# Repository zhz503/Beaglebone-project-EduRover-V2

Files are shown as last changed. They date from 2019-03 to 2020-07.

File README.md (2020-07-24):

# BeagleBone project--EduRover(version2)

### Project Description:

This is an application of the embedded system: Beaglebone. EduRover is originally designed by James Strawson(jstrawso@eng.ucsd.edu) in the Drone Lab and Coordinated Robotics Lab, @UCSD. In version 2, we made some modification on it, redesigned some part of it. In our case, high torque motors could be perfectly embedded into our design and with the higher level control algorithm, we can manually drive EduRover in different modes. Meanwhile, with the high torque motors, we can balance EduRover by using only two wheels when it faces the wall.      

For more details, please check the report:

https://github.com/zhz503/Beaglebone-project-EduRover-V2/blob/master/doc/EduRover_report.pdf

### Team Member:

Zhaoliang Zheng (zhz503@eng.ucsd.edu)

Dominique E. Meyer (demeyer@ucsd.edu)

Neal Bansal (nkbansal@ucsd.edu)

Pengcheng Cao (p5cao@eng.ucsd.edu)

Junchao Lin (jul025@eng.ucsd.edu)

### EduRover V2:
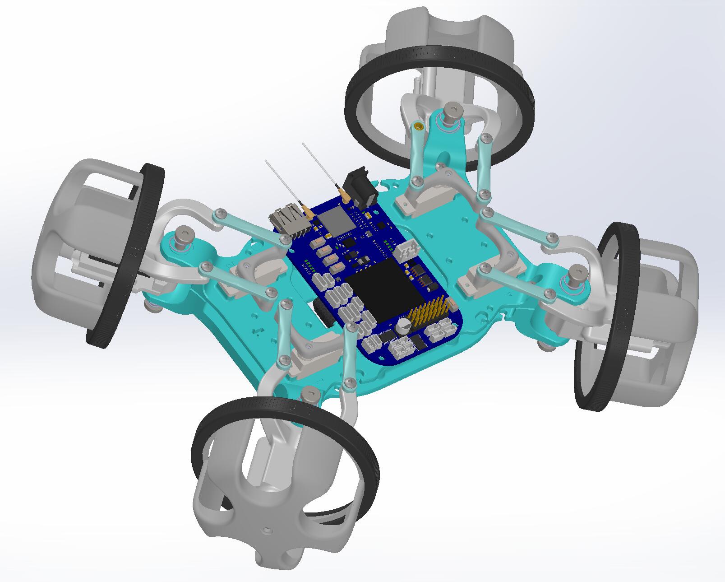
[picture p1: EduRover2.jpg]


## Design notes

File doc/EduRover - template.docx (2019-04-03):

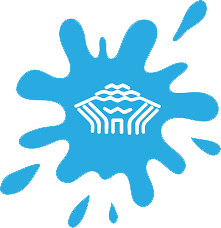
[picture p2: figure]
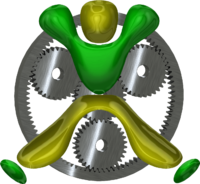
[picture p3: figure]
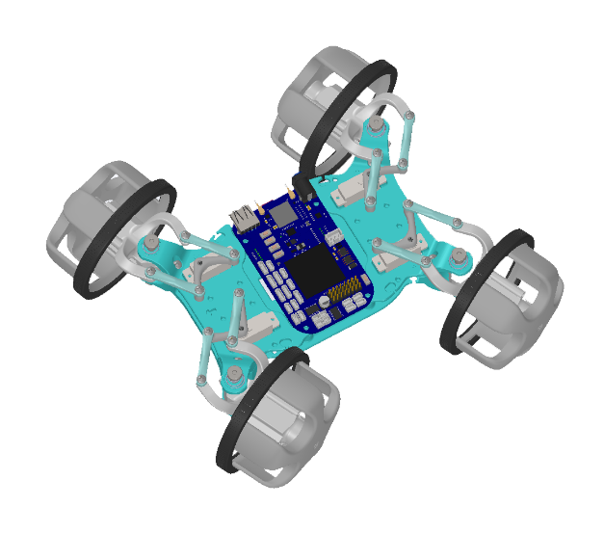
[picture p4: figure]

TEAM MEMBERS:

Zhaoliang Zheng (zhz503@eng.ucsd.edu)

Dominique Meyer (demeyer@ucsd.edu)

Neal Bansal (nkbansal@ucsd.edu)

Pengcheng Cao (p5cao@eng.ucsd.edu)

Junchao Lin (jul025@eng.ucsd.edu)

BeagleBone Project

# EduRover V2

# 0 Introduction

This is an application of the embedded system: Beaglebone. EduRover is originally designed by James Strawson (jstrawso@eng.ucsd.edu) in the Done Lab@UCSD and Coordinated Robotics Lab@UCSD. In version 2, we made some modification on it, redesigned some part of it. In our case, high torque motors could be perfectly embedded into our design and with the higher level control algorithm, we can manually drive EduRover in different modes. Meanwhile, with the high torque motors, we can balance EduRover by using only two wheels when it faces the wall.

# 1 Structure

This chapter describes the structure and some hardware of EduRover as well as the properties of these components. All the Solidworks files can be found in the link: https://github.com/zhz503/Beaglebone-project-EduRover-V2/tree/master/Edu%20Rover%20Solidworks%20Version2

1.1 Configuration in different modes
The figure 1-1 shows the structure of EduRover and in the balance condition.

The figure 1-2 shows the different four-wheeled EduRover driving mode.

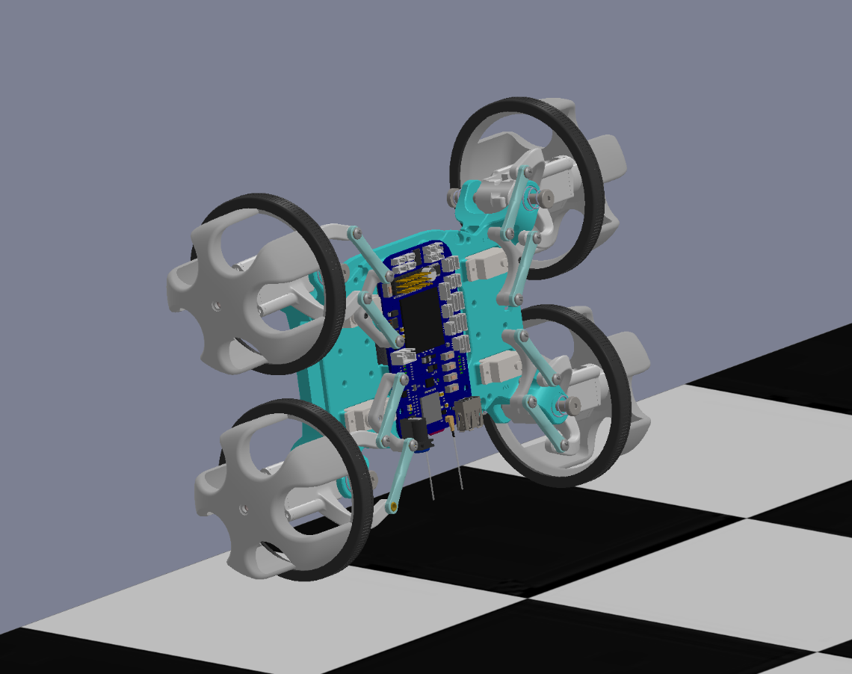
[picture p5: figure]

Figure 1-1 Balance Configuration Mode

(a) (b)

(c) (d)

Figure 1-2 (a) is Spinning Mode, (b) is Normal-car Mode, (c) is Quarter Turn Mode, (d) is Sidling Mode

## 1.2 Sensors and Actuators

Table 1-1 Sensors

Sensor | Output | Unit
Encoder | Angle | rad or deg
IMU: Gyroscope | Angular velocity | deg/sec
IMU: Accelerometer | Linear velocity | m/sec

Table 1-2 Actuators

Actuator | Output | Unit
Servo Motor | Position or duty circle | %
DC Motor | PWM | %

The illustration of DC motor[1] and Servo Motor can be found in appendix A and reference.

# 2 Mathematical Modeling

This chapter describes the mathematical model and motion equations of EduRover. Based on the basic knowledge, the EduRover balance mode can be simplified as a two-wheeled inverted pendulum model[2], and EduRover four-wheeled normal-car mode can be simplified as Ackermann drive (bicycle) model. Spining Mode, Quarter Turn Mode, Sidling Mode can be simplified as Omni Wheel model.

## 2.1 Notation

Items | Parameter | Value | Unit | Meaning
EduRover Parameter | g | 9.81 | m/sec^2 | Gravity acceleration
| m | 0.03852 | kg | Wheel weight
| R | D/2= 0.0425 | m | Wheel radius
| J_w | mR^2 /2 | kgm^2 | Wheel inertia moment
| M | 0.6 | kg | Body weight
| W | 0.150 | m | Body width
| D | 0.048 | m | Body depth
| H | 0.18282 | m | Body height
| L | 0.08869 | m | Distance of the center of mass from the wheel axle
| J_ψ | ML^2 /3 | kgm^2 | Body pitch inertia moment
| J_ϕ | M(W^2 +D^2 )/12 | kgm^2 | Body yaw inertia moment
| f_m | 0.0022 | | Friction coefficient between body & DC motor
| f_w | Depends[4]:0.1 | | Rolling Friction between wheel & floor
DC motor | T_(or) | 0.1765 | Nm | Motor torque
| I_m | 1.6 | A | Motor working current
| J_m | 2.7565e^(-) 7 | kgm^2 | DC motor inertia moment
| R_m | 2.7 | Ω | DC motor resistance
| K_b | 7.407e^(-) 4 | Vsec/rad | DC motor back EMF constant
| K_t | T_(or) /I_m | Nm/A | DC motor torque constant
| n | 99 | | Gear ratio

Note:

DC motor parameters can be found in [1].

f_m ,f_w are hard to verify, so they are a approximation.

[4] Rubber & Concrete(Dry)

## 2.2 Two-wheeled Inverted Pendulum Model and Differential-drive Model

The EduRover can be simplified as a two-wheeled inverted pendulum model, as described in Figure 2.2-1

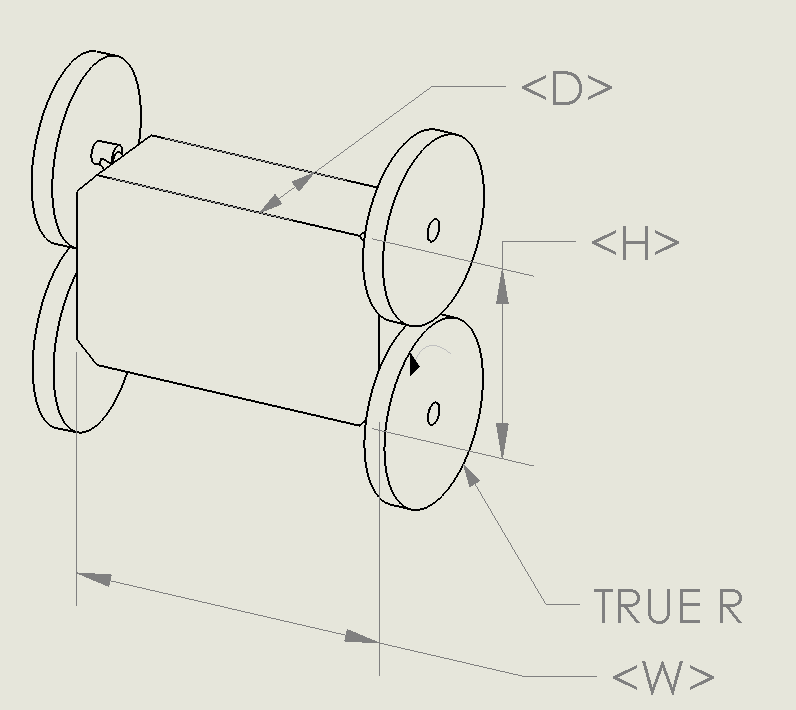
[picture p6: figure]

Figure 2.2-1 Two-wheeled Inverted Pendulum Model

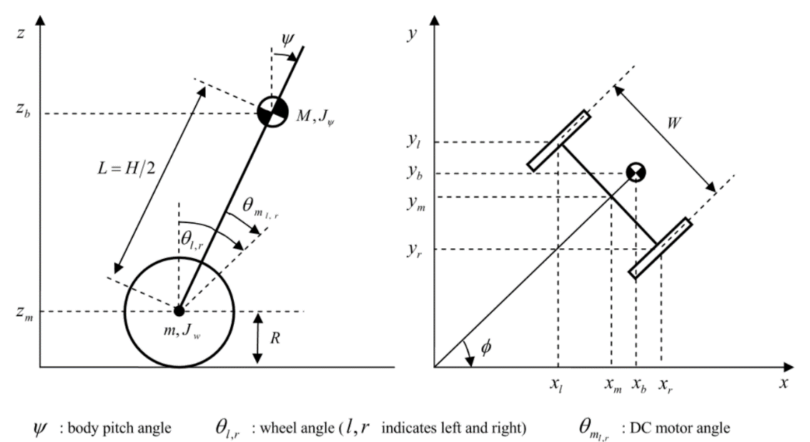
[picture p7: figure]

Figure 2.2-2 Side view and plane view of the model

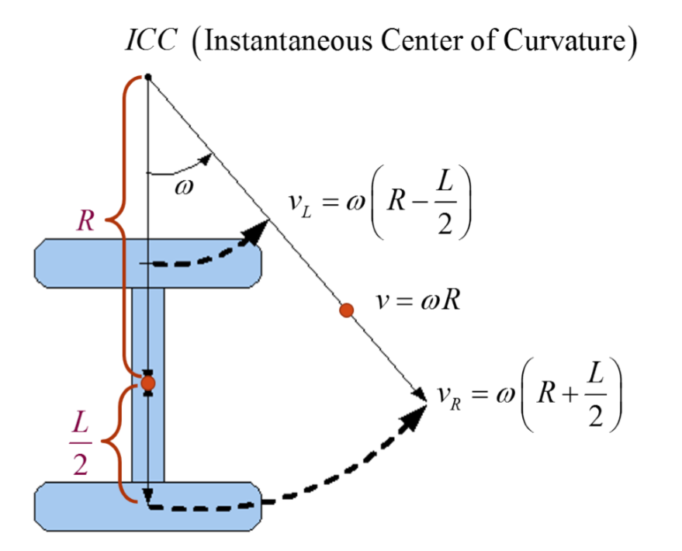
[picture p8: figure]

Figure 2.2-3 Differential-drive Model

### 2.2.1 Motion equations of two-wheeled inverted pendulum

We can derive motion equations for inverted pendulum based on figure 2.2-2 and the differential model in figure 2.2-3 differential-drive model [3].

[F_θ , F_ψ , F_ϕ ]^T =[1/2(F_l +F_r ), F_ψ , R/W(F_r -F_l )]^T

[x_m , y_m , z_m ]^T =[Rθcosϕ, Rθsinϕ, R]^T

[θ, ϕ]^T = [1/2(θ_l +θ_r ), R/W(θ_r -θ_l )]^T

[x_l , y_l , z_l ]^T =[x_m -W/2sinϕ, y_m +W/2cosϕ, z_m ]^T

[x_r , y_r , z_r ]^T =[x_m +W/2sinϕ, y_m -W/2cosϕ, z_m ]^T

[x_b , y_b , z_b ]^T =[x_m +Lsinψcosϕ, y_m +Lsinψsinϕ, z_m +Lcosψ]^T

Where,

θ : average rotational angle of left and right wheel

ψ : Body pitch angle

ϕ : Body yaw angle

Based on the kinetic energy theorem and the potential energy theorem, the translational kinetic energy E_(k1) and the rotational kinetic energy E_(k2) , the potential energy E_p are:

E_(k1) =1/2m(x_l ^2 +y_l ^2 +z_l ^2 )+1/2m(x_r ^2 +y_r ^2 +z_r ^2 )+1/2M(x_b ^2 +y_b ^2 +z_b ^2 )

E_(k2) =1/2J_w θ_l ^2 +1/2J_w θ_r ^2 +1/2J_ψ ψ^2 +1/2J_ϕ ϕ^2 +1/2n^2 J_m (θ_l -ψ)^2 +1/2n^2 J_m (θ_r -ψ)^2

E_p =mgz_l +mgz_r +Mgz_b

Note: the last two terms in E_(k2) equation are the rotational kinetic energy of armature in the left and right DC motor.

### 2.2.2 Lagrangian equations

Based on the Lagrangian method, The Lagrangian L has the following expression:

L=E_(k1) +E_(k2) -E_p

We use the variables θ,ψ,ϕ as the generalized coordinate. The Lagrangian equation can be derived as:

d/(dt)((∂L)/(∂ θ))-(∂L)/(∂θ)=F_θ

d/(dt)((∂L)/(∂ ψ))-(∂L)/(∂ψ)=F_ψ

d/(dt)((∂L)/(∂ ϕ))-(∂L)/(∂ϕ)=F_ϕ

Expand the equations ()-(), we can derive the following equations, the whole derivation is in the Appendix:

((2m+M)R^2 +2J_w +2n^2 J_m )θ+(MLRcosψ-2n^2 J_m )ψ-MLRsinψ ψ^2

-((2m+M)R^2 θ+MLRsinψ)ϕ^2 =F_θ

(ML^2 +J_ψ +2n^2 J_m )ψ+(-2n^2 J_m +MLRcosψ)θ-MgLsinψ

-(MLRθ+ML^2 sinψ)ϕ^2 cosψ=F_ψ

((mW^2)/2+(W^2)/(2R^2)(J_w +n^2 J_m )+J_ϕ +2MLRθsinψ+(2m+M)R^2 θ^2 )ϕ+2(2m+M)R^2 θθϕ+2ML^2 sinψcosψ ψϕ+2MLRϕ(θsinψ+cosψ θψ)=F_ϕ

Considering the rolling friction between motor and wheel as well as the friction between wheel and floor, the generalized force are:

F_l =nK_t i_l +f_m (ψ-θ_l )-f_w θ_l

F_r =nK_t i_r +f_m (ψ-θ_r )-f_w θ_r

F_ψ =-nK_t i_r -nK_t i_l -f_m (ψ-θ_r )-f_m (ψ-θ_l )

Where i_(l,r) is DC motor current.

Since the input of our system is voltage of DC motor, in the above equations, we cannot used current i_(l,r) directly. Therefore, we have to derive the relationship between current i_(l,r) and voltage ν_(l,r) . From DC motor model, The applied voltage equals the voltage drop across the coil resistance, R, and the inductor, L, plus the back-EMF[5], which is as follows:[4]:

ν_(l,r) =i_(l,r) R_m +L_m (di_(l,r))/(dt)+K_b (ψ-θ_(l,r) )

Where, R_m : DC motor resistance, L_m : DC motor inductance.

For the steady-state torque-speed relationship, L_m has no effect, so L_m term is negligible and is approximated as zero. Therefore, rewrite equation() as:

i_(l,r) =(ν_(l,r) -K_b (ψ-θ_(l,r) ))/(R_m)

When substitute the equation() to equations()-(), the generalized force can be expressed as the function of voltage:

F_θ =α/2(ν_l +ν_r )-(β+f_w )θ+βψ

F_ψ =-α(ν_l +ν_r )+2βθ-2βψ

F_ϕ =R/Wα(ν_l -ν_r )-(β+f_w )ϕ

Where, α=(nK_t)/(R_m), β=(nK_t K_b)/(R_m)+f_m

### 2.2.3 State equation linearization

So far, we’ve had all the equations we need. At the balance point, when the body angle ψ changes at about ±5^(°) , equation() can be linearized. In this case, ψ approximates to be 0, meaning that sin ψ≈0,cosψ≈1 , and ψ^2 ≈0 . The linearized Lagrangian equations() can be rewritten as follows:

((2m+M)R^2 +2J_w +2n^2 J_m )θ+(MLRcosψ-2n^2 J_m )ψ=F_θ

(ML^2 +J_ψ +2n^2 J_m )ψ+(MLR-2n^2 J_m )θ-MgLψ=F_ψ

((mW^2)/2+(W^2)/(2R^2)(J_w +n^2 J_m )+J_ϕ )ϕ=F_ϕ

Now, we can combine the equ()-() and the equations()-(), and rewrite these equations in matrix form:

{E[θψ]+F[θψ]+G[θψ]=H[ν_l ν_r ]Iϕ+Jϕ=K(ν_l -ν_r )

Where,

E=[(2m+M)R^2 +2J_w +2n^2 J_m , MLRcosψ-2n^2 J_m MLR-2n^2 J_m , ML^2 +J_ψ +2n^2 J_m ]

F=[β+f_w , -β-2β, 2β] , G=[0, 00, -MgL] , H=[α/2, α/2-α, -α]

I= (mW^2)/2+(W^2)/(2R^2)(J_w +n^2 J_m )+J_ϕ

J=β+f_w

K= R/Wα

Now, we can consider x_1 =[θ, ψ, θ, ψ]^T , x_2 =[ϕ, ϕ] as the state, u=[ν_l , ν_r ]^T as input, we can rewrite equations() as state space equations form:

x_1 =A_1 x_1 +B_1 u

x_2 =A_2 x_2 +B_2 u

The state space realization:

A_1 =[0, 00, 0, 1, 00, 10, A_1 (3,2)0, A_1 (4,2), A_1 (3,3), A_1 (3,4)A_1 (4,3), A_1 (4,4)] , B_1 =[0, 00, 0B_1 (3), B_1 (3)B_1 (4), B_1 (4)]

A_2 =[0, 10, -J/I] , B_2 =[0, 0-K/I, K/I]

Where, in the MATLAB:

det(E)=E(1,1)E(1,2)-E(1,2)^2

A_1 (3,2)=-MgLE(1,2)/det⁡(E)

A_1 (4,2)=MgLE(1,1)/det⁡(E)

A_1 (3,3)=-((β+f_w )E(2,2)+2βE(1,2))/(det(E))

A_1 (4,3)=((β+f_w )E(1,2)+2βE(1,1))/(det(E))

A_1 (3,4)=(β(E(2,2)+2E(1,2)))/(det(E))

A_1 (4,4)=-(β(E(1,2)+2E(1,1)))/(det(E))

B_1 (3)=(α(E(2,2)/2+E(1,2)))/(det(E))

B_1 (4)=-(α(E(1,2)/2+E(1,1)))/(det(E))

# 3 Control system design

## 3.1 Control System Theory

### 3.1.1 Input & Output

A. Balance Mode

Input : ν= [ν_l , ν_r ]^T

Output: x=[θ ψ θ ψ]^T

B. Four-wheeled modes

Input: u=[flag K_m K_s ]

Output: x=[Mo_1234 Ser_1234 ]

### 3.1.2 Stability

(not yet finish)

## 3.2 Controller design

### 3.2.1 Equivalent system for balance mode

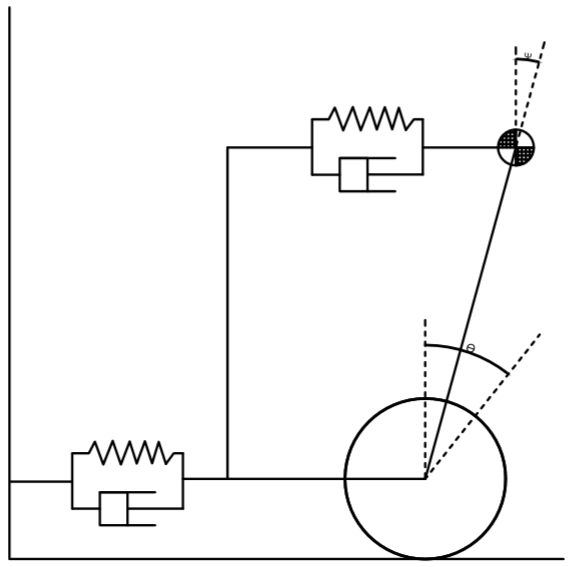
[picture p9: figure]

Figure 3.2-1

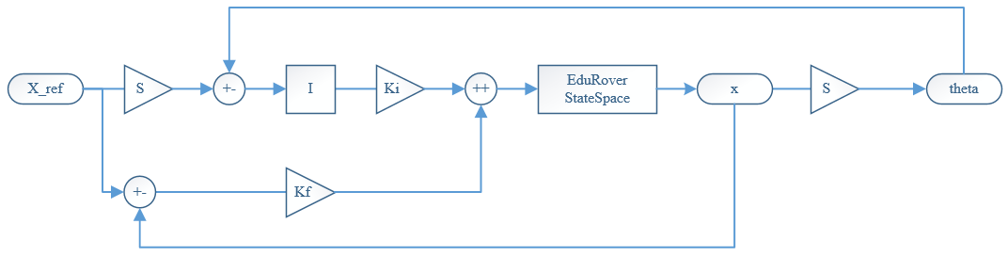
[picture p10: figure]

Figure 3.2-2

### 3.2.2 Simulation

A. Balance Mode

The EduRover balance mode can only be activated when it faces the wall. In the simulation, we only consider the small angle approximation, which is around 5^(°) . We can set the initial condition: ψ=5^(°) . The simulation runs in Simulink. The result is as follows.

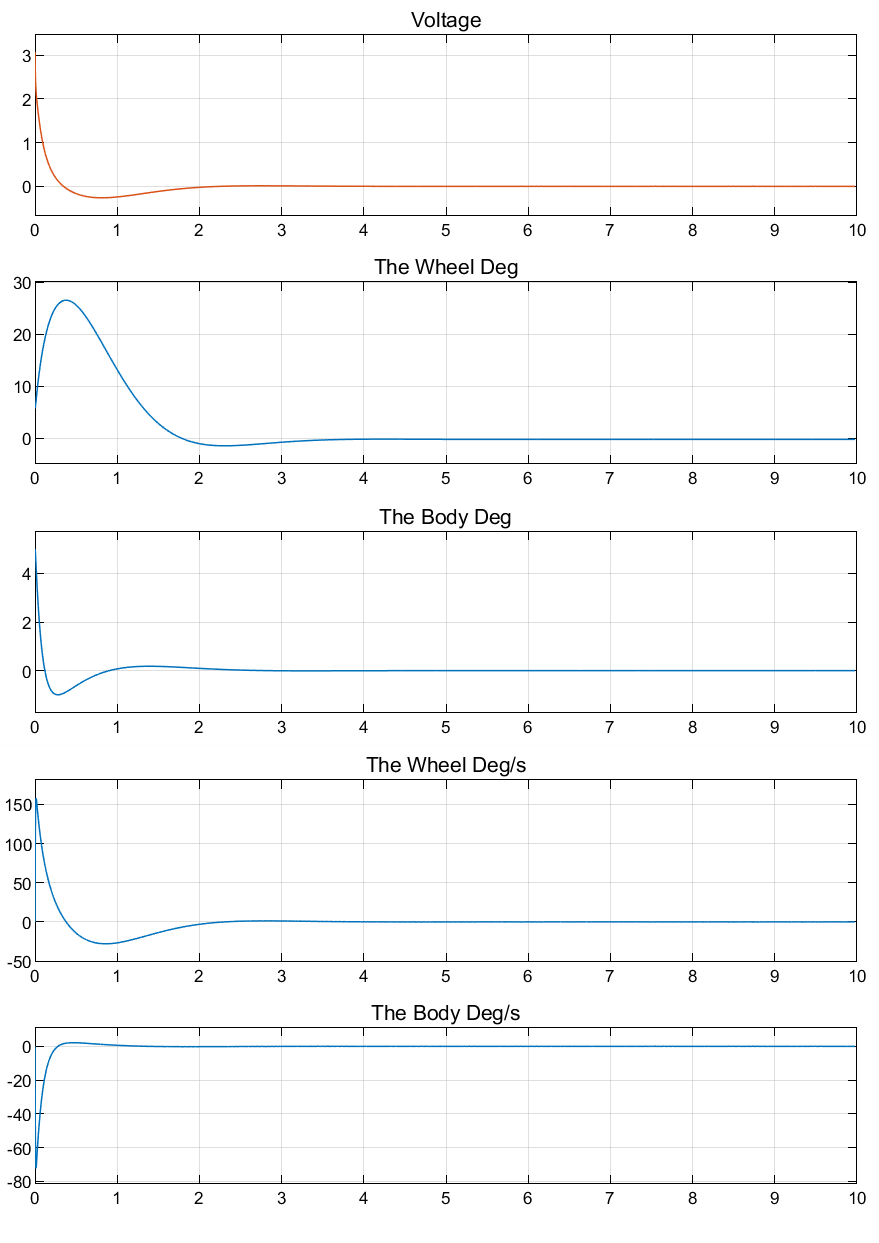
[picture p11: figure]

Figure 3.2-1

B. Four-wheeled driving mode

In the four-wheeled driving mode, four situation has to be consider: (a) Spinning mode, (b) Normal-car mode, (c) Quarter-turn mode, (d) Sidling mode. To switch from different modes, we have set up a servo logic for these four different modes.

For manual control, we want to minimize the number of inputs as much as possible. The figure 3.2-2 shows that the servo logics in Simulink. In this servo logics, the flag constant controls the logics switching between different modes. Flag(1): Spinning Mode, flag(2): Normal Car Mode, flag(3): Quarter Turn Mode, flag(4): Sidling Mode.

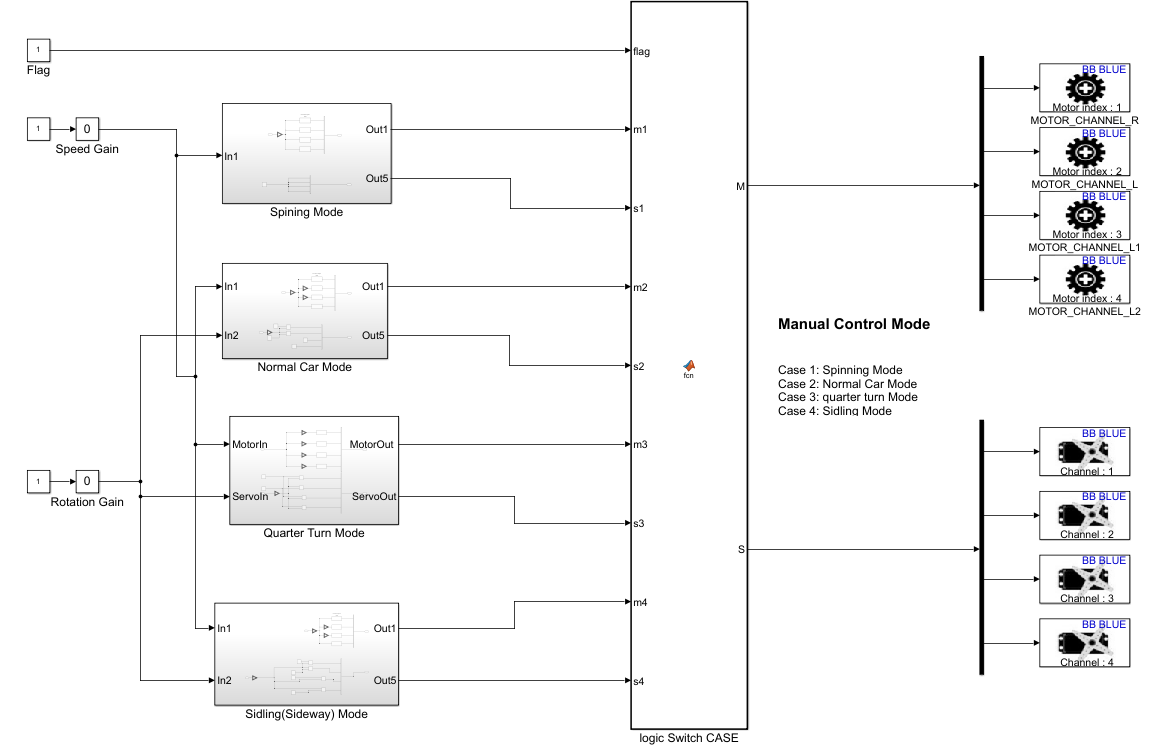
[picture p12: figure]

Figure 3.2-2 Servo logics

3.2.3 Real-world Experiment

A. Balance Mode

(not yet finish)

B. Four-wheeled driving mode

We can use the controller designed in Simulink to control the EduRover in real-time in real-world. The following video links can show you how it performs:

(1) https://github.com/zhz503/Beaglebone-project-EduRover-V2/blob/master/RW%20Simulink%20Control%20and%20Sensing/ManualControl.mp4
(2) https://github.com/zhz503/Beaglebone-project-EduRover-V2/blob/master/RW%20Simulink%20Control%20and%20Sensing/logics%20switch.MP4

# 4 Higher level application design

EduRover is a very decent platform for developer to do higher level application design. There are many applications right now.

In this report, I only list some of the on-going applications:

(1) Way points following based on Motion Capture system

(2) Path planning algorithm based on Motion Capture system

(3) Feature recognition based on web cam on board

(4) ORB-SLAM based on RGBD camera

## 4.1 Way points following based on Motion Capture system

### 4.1.1 Closed loop feedback control

(not yet finish)

### 4.1.2 Motion Capture System

In this project, the motion capture system we used is VICON system. According to the description [5], Vicon are the premier solution for UAV and Robotic studies because we understand what is important; A highly accurate system that provides low latency data that is easy to use. With our turnkey approach and easy to access our DataStream (via TCP, UDP, etc.) users can easily integrate accurate Vicon data into virtually any control system.

### 4.1.3 PID Control Algorithm

This PID control algorithm is designed by Dominique Meyer, which is available in the Github: https://github.com/zhz503/Beaglebone-project-EduRover-V2/tree/master/way_points%20following

## 4.2 Path planning Algorithm on board

### 4.2.1 Workflow

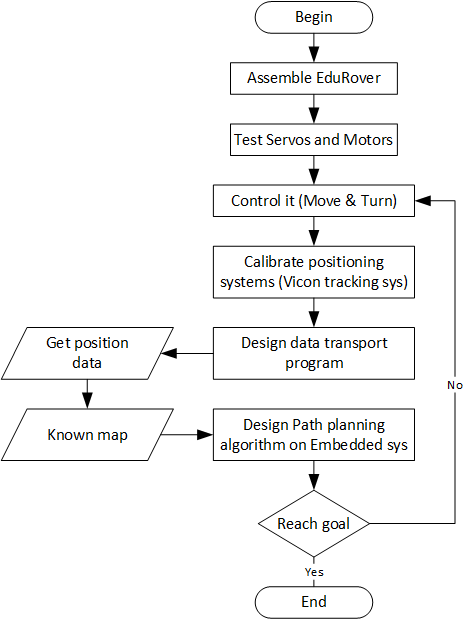
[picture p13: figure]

Figure 4-1

# Appendix A Table 1-3 Servo Motor Properties

Table 1-3 Servo Motor Properties

Product | Seller | Link | No-Load Speed @ 4.8V (sec/60°) | Price | Qty | Price/Unit
HS-45HB | ServoCity | https://www.servocity.com/hs-45hb-servo | 0.14 | $15.99 | 1 | $15.99
RB-Fit-03 | RobotShop | https://www.robotshop.com/en/9g-micro-servo-motor-4-8v.html#Supplier-Product-Code | 0.12 | $3.56 | 1 | $3.56
Miuzei SG90 | Amazon | https://www.amazon.com/Micro-Helicopter-Airplane-Remote-Control/dp/B072V529YD?ref_=fsclp_pl_dp_1&th=1 | 0.09 | $17.99 | 10 | $1.80
Seamuing MG90S | Amazon | https://www.amazon.com/dp/B07F7VJQL5/ref=psdc_2234131011_t2_B072V529YD?th=1 | 0.11 | $20.99 | 6 | $3.50
SG90 Micro Servo | Amazon | https://www.amazon.com/dp/B07F2XDZZ7/ref=psdc_2234131011_t2_B072V529YD?th=1 | 0.1 | $19.99 | 10 | $2.00

# Appendix B The derivation of Lagrangian equations

{x_l =Rθcosϕ-Wsinϕ/2x_r =Rθcosϕ+Wsinϕ/2x_b =Rθcosϕ+Lsinψcosϕ{x_l =Rθcosϕ-Rθsinϕ ϕ-Wϕcosϕ/2x_r =Rθcosϕ-Rθsinϕ ϕ+Wϕcosϕ/2x_b =Rθcosϕ-Rθsinϕ ϕ+Lψcosψcosϕ-Lϕsinψsinϕ

x_l ^2 +x_r ^2 =2(Rθcosϕ-Rθsinϕ ϕ)^2 + W^2 ϕ^2 cos^2 ϕ/2

{y_l =Rθsinϕ+Wcosϕ/2y_r =Rθsinϕ-Wcosϕ/2y_b =Rθsinϕ+Lsinψsinϕ{y_l =Rθsinϕ+Rθcosϕ ϕ-Wϕsinϕ/2y_r =Rθsinϕ+Rθcosϕ ϕ+Wϕsinϕ/2y_b =Rθsinϕ+Rθcosϕ ϕ+Lψcosψsinϕ+Lϕsinψcosϕ

y_l ^2 +y_r ^2 =2(Rθsinϕ+Rθcosϕ ϕ)^2 + W^2 ϕ^2 sin^2 ϕ/2

{z_l =Rz_r =Rz_b =R+Lcosψ{z_l =0z_r =0z_b =-Lψsinψ

E_(k1) =1/2m(x_l ^2 +y_l ^2 +z_l ^2 )+1/2m(x_r ^2 +y_r ^2 +z_r ^2 )+1/2M(x_b ^2 +y_b ^2 +z_b ^2 )=?

{θ=1/2(θ_l +θ_r )ϕ=R/W(θ_r -θ_l ){θ_l =θ-W/(2R)ϕθ_r =θ+W/(2R)ϕ{θ_l =θ-W/(2R)ϕθ_r =θ+W/(2R)ϕ

{(θ_l -ψ)^2 =(θ-W/(2R)ϕ-ψ)^2 (θ_r -ψ)^2 =(θ+W/(2R)ϕ-ψ)^2 (θ_l -ψ)^2 +(θ_r -ψ)^2 =2(θ-ψ)^2 +(W/(2R)ϕ)^2

E_(k2) =1/2J_w θ_l ^2 +1/2J_w θ_r ^2 +1/2J_ψ ψ^2 +1/2J_ϕ ϕ^2 +1/2n^2 J_m (θ_l -ψ)^2 +1/2n^2 J_m (θ_r -ψ)^2 =?

E_p =mgz_l +mgz_r +Mgz_b =2mgR+Mg(R+Lcosψ)

L=E_(k1) +E_(k2) -E_p =?

(∂L)/(∂ θ)=1/2((2m+M)R^2 (2θ)+MLRψcosψ)+2J_w θ+2n^2 J_m (θ-ψ)

(∂L)/(∂θ)=?

d/(dt)((∂L)/(∂ θ))=?

(∂L)/(∂ ψ)=?

(∂L)/(∂ψ)=？

d/(dt)((∂L)/(∂ ψ))=？

(∂L)/(∂ ϕ)=？

(∂L)/(∂ϕ)=？

d/(dt)((∂L)/(∂ ϕ))=？

{((2m+M)R^2 +2J_w +2n^2 J_m )θ+(MLRcosψ-2n^2 J_m )ψ-MLRsinψ ψ^2 -((2m+M)R^2 θ+MLRsinψ)ϕ^2 =F_θ (ML^2 +J_ψ +2n^2 J_m )ψ+(-2n^2 J_m +MLRcosψ)θ-MgLsinψ-(MLRθ+ML^2 sinψ)ϕ^2 cosψ=F_ψ ((mW^2)/2+(W^2)/(2R^2)(J_w +n^2 J_m )+J_ϕ +2MLRθsinψ+(2m+M)R^2 θ^2 )ϕ+2(2m+M)R^2 θθϕ+2ML^2 sinψcosψ ψϕ+2MLRϕ(θsinψ+cosψ θψ)=F_ϕ

# Reference

[1] https://www.servocity.com/270-rpm-micro-gear-motor-w-encoder
[2] NXTway-GS Model-Based Design, http://www.pages.drexel.edu/~dml46/Tutorials/BalancingBot/files/NXTway-GS%20Model-Based_Design.pdf
[3] UCSD ECE motion and observation model, https://natanaso.github.io/ece276a/ref/ECE276A_8_MotionObservationModels.pdf
[4] https://www.motioncontroltips.com/faq-whats-relationship-voltage-dc-motor-output-speed/
[5] https://www.vicon.com/motion-capture/engineering

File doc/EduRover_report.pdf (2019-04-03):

# EDUROVER V2

# BeagleBone Project

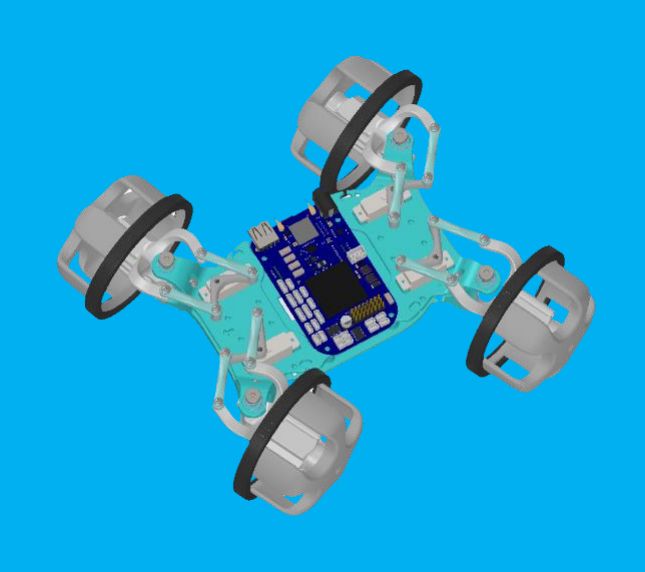
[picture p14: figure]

### TEAM MEMBERS:

### Zhaoliang Zheng (zhz503@eng.ucsd.edu)

### Dominique Meyer (demeyer@ucsd.edu)

### Neal Bansal (nkbansal@ucsd.edu)

### Pengcheng Cao (p5cao@eng.ucsd.edu)

### Junchao Lin (jul025@eng.ucsd.edu)

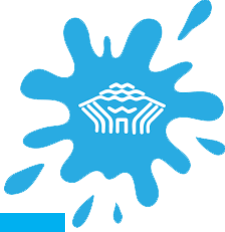
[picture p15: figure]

2 / 18

## Catalog

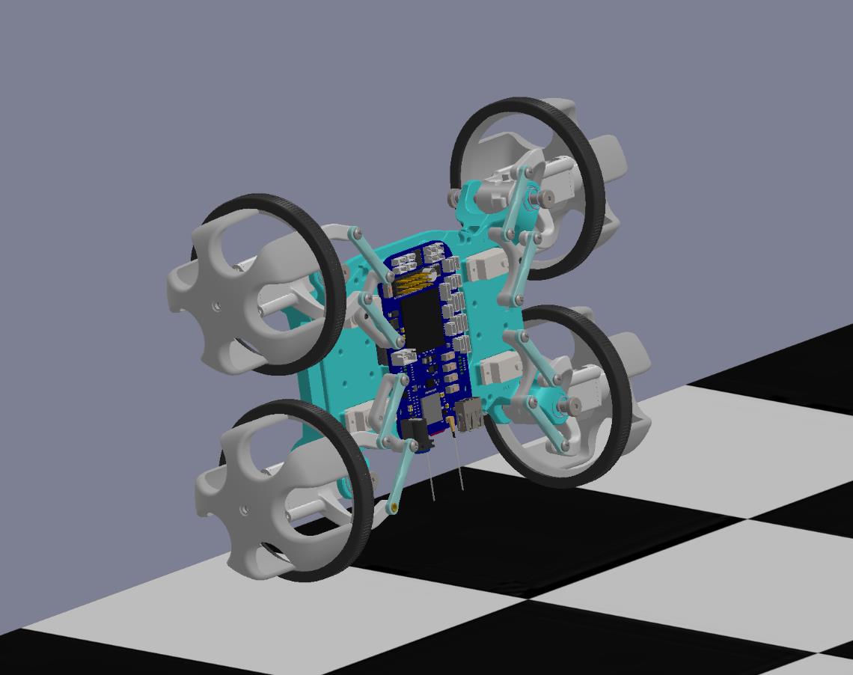
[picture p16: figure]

3 / 18

### 0 INTRODUCTION

This is an application of the embedded system: Beaglebone. EduRover is originally designed by James Strawson (jstrawso@eng.ucsd.edu) in the Done Lab@UCSD and Coordinated Robotics Lab@UCSD. In version 2, we made some modification on it, redesigned some part of it. In our case, high torque motors could be perfectly embedded into our design and with the higher level control algorithm, we can manually drive EduRover in different modes. Meanwhile, with the high torque motors, we can balance EduRover by using only two wheels when it faces the wall.

### 1 STRUCTURE

This chapter describes the structure and some hardware of EduRover as well as the properties of these components. All the Solidworks files can be found in the link: https://github.com/zhz503/Beaglebone-project-EduRover-V2/tree/master/Edu%20Rover%20Solidworks%20Version2 (https://github.com/zhz503/Beaglebone-project-EduRover-V2/tree/master/Edu%20Rover%20Solidworks%20Version2)

### 1.1 Configuration in different modes

The figure 1-1 shows the structure of EduRover and in the balance condition.

The figure 1-2 shows the different four-wheeled EduRover driving mode.

Figure 1-1 Balance Configuration Mode

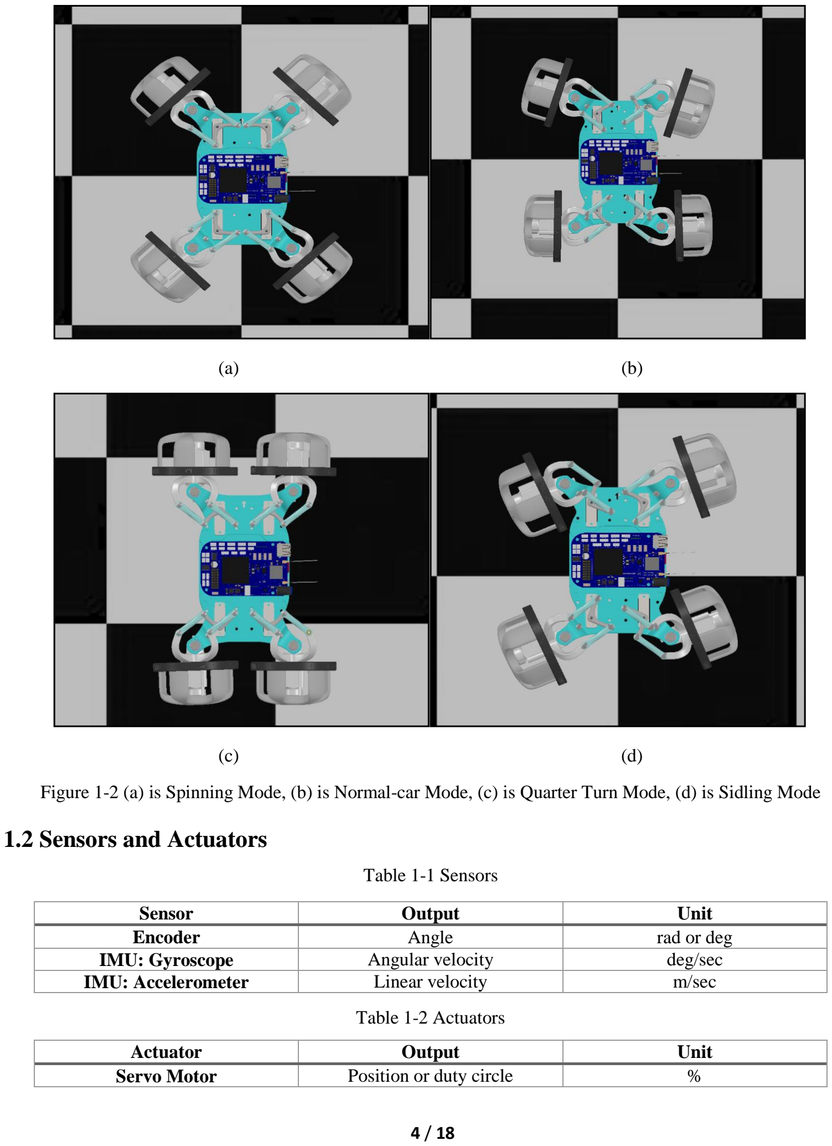
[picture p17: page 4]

4 / 18

(a) (b)
(c) (d)

Figure 1-2 (a) is Spinning Mode, (b) is Normal-car Mode, (c) is Quarter Turn Mode, (d) is Sidling Mode

### 1.2 Sensors and Actuators

Table 1-1 Sensors

Sensor | Output | Unit
Encoder | Angle | rad or deg
IMU: Gyroscope | Angular velocity | deg/sec
IMU: Accelerometer | Linear velocity | m/sec

Table 1-2 Actuators

Actuator | Output | Unit
Servo Motor | Position or duty circle | %

5 / 18

DC Motor | PWM | %

The illustration of DC motor[1] and Servo Motor can be found in appendix A and reference.

6 / 18

### 2 MATHEMATICAL MODELING

This chapter describes the mathematical model and motion equations of EduRover. Based on the basic knowledge, the EduRover balance mode can be simplified as a two-wheeled inverted pendulum model[2], and EduRover four-wheeled normal-car mode can be simplified as Ackermann drive (bicycle) model. Spining Mode, Quarter Turn Mode, Sidling Mode can be simplified as Omni Wheel model.

### 2.1 Notation

Items | Parameter | Value | Unit | Meaning EduRover Parameter
g | 9.81 | m/sec² | Gravity acceleration
m | 0.03852 | kg | Wheel weight
R | D/2 =0.0425 | m | Wheel radius
Jw | mR

2

/2 | kgm² | Wheel inertia moment
M | 0.6 | kg | Body weight
W | 0.150 | m | Body width
D | 0.048 | m | Body depth
H | 0.18282 | m | Body height
L | 0.08869 | m | Distance of the center of mass from the wheel axle
Jψ | ML

2
/3 | kgm² | Body pitch inertia moment
| Jφ | M(W² + D
| | 2
)/12 kgm² | Body yaw inertia moment
fm | 0.0022 | Friction coefficient between body & DC motor
fw | Depends[4]:0.1 | Rolling Friction between wheel & floor

DC motor

Tor | 0.1765 | Nm | Motor torque
Im | 1.6 | A | Motor working current
| Jm | 2.7565e
−7 | kgm² | DC motor inertia moment
Rm | 2.7 | Ω | DC motor resistance
| Kb | 7.407e
−4 | Vsec/rad | DC motor back EMF constant
Kt | Tor/Im | Nm/A | DC motor torque constant
n | 99 | Gear ratio
Note:

DC motor parameters can be found in [1].

fm, fw are hard to verify, so they are a approximation.

[4] Rubber & Concrete(Dry)

### 2.2 Two-wheeled Inverted Pendulum Model and Differential-drive Model

The EduRover can be simplified as a two-wheeled inverted pendulum model, as described in Figure 2.2-1

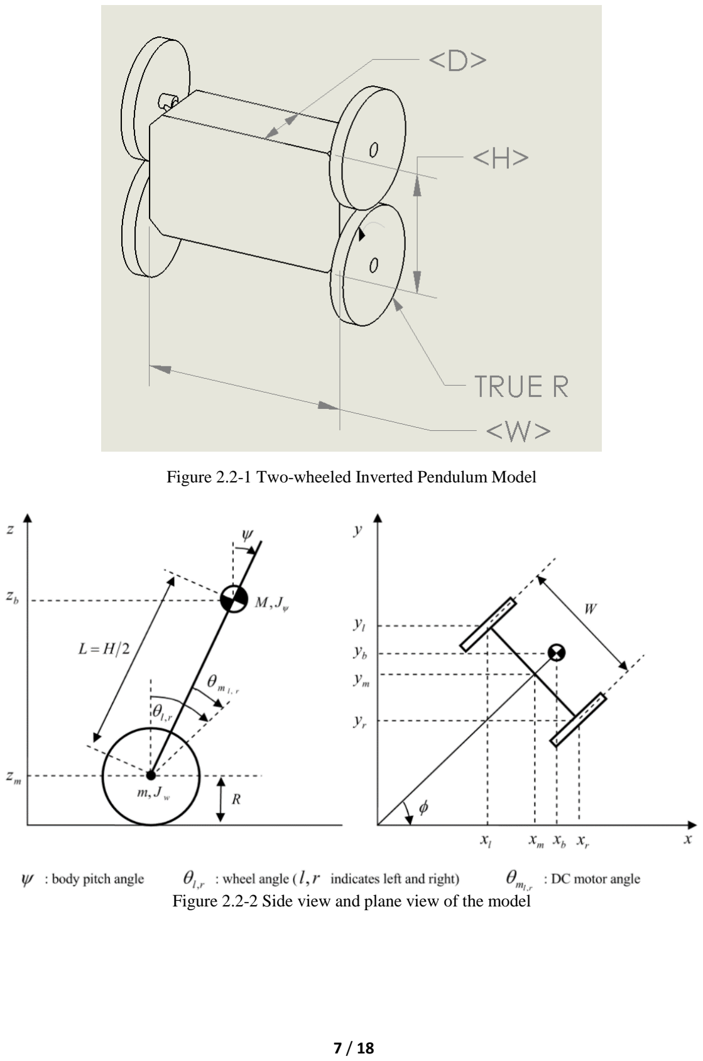
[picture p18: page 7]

7 / 18

Figure 2.2-1 Two-wheeled Inverted Pendulum Model

Figure 2.2-2 Side view and plane view of the model

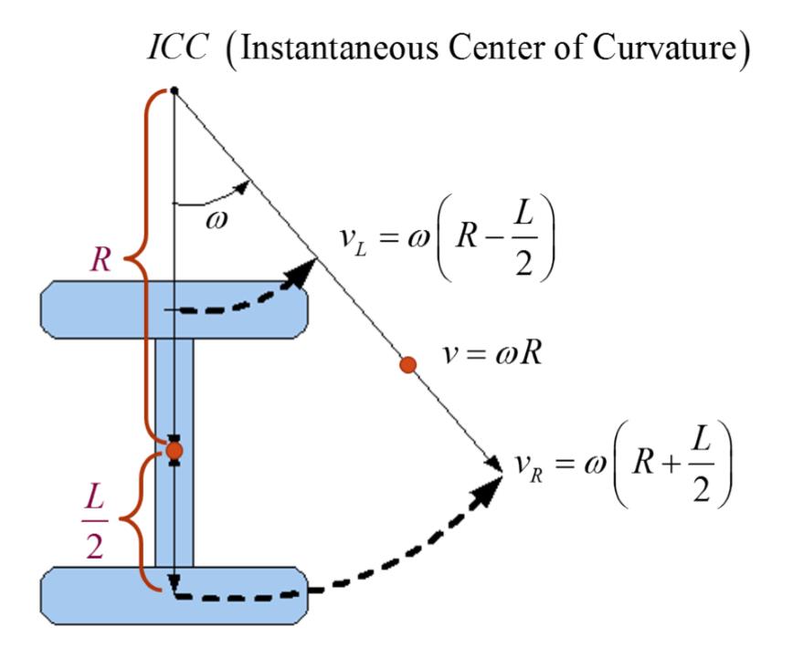
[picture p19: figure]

8 / 18

Figure 2.2-3 Differential-drive Model

### 2.2.1 Motion equations of two-wheeled inverted pendulum

We can derive motion equations for inverted pendulum based on figure 2.2-2 and the differential model in figure 2.2-3 differential-drive model [3].

[Fθ | Fψ | Fφ]

T = [

1
2

(Fl + Fr) Fψ

R
W

(Fr − Fl)]

T

[xm | ym | zm]

T = [Rθ cosφ Rθ sinφ R]

T

[θ φ]

T = [

1
2

(θl + θr)

R
W

(θr − θl)]

T

[xl | yl | zl] T = [xm −

W
2

sinφ ym +

W
2

cosφ zm]

T

[xr | yr | zr]

T = [xm +

W
2

sinφ ym −

W
2

cosφ zm]

T

[xb | yb | zb]

T = [xm + L sin ψ cosφ ym + L sin ψ sinφ zm + L cos ψ]

T

Where,

θ : average rotational angle of left and right wheel

ψ: Body pitch angle

φ: Body yaw angle

9 / 18

Based on the kinetic energy theorem and the potential energy theorem, the translational kinetic energy Ek1 and the rotational kinetic energy Ek2, the potential energy Ep are:

Ek1 =

1
2

m(xl
̇

2 + yl
̇

2 + zl
̇

2
) +

1
2

m(xr
̇

2 + yr
̇

2 + zr
̇

2
) +

1
2

M(xḃ

2 + yḃ

2 + zḃ

2
)

Ek2 =

1
2

Jwθl

̇

2
+

1
2

Jwθr

̇

2
+

1
2

Jψψ̇² +

1
2

Jφφ̇² +

1
2

n

2
Jm(θl

̇ − ψ̇)
2 +

1
2

n

2
Jm(θr

̇ − ψ̇)
2

Ep = mgzl + mgzr + Mgzb

Note: the last two terms in Ek2 equation are the rotational kinetic energy of armature in the left and right DC motor.

### 2.2.2 Lagrangian equations

Based on the Lagrangian method, The Lagrangian L has the following expression:

L = Ek1 + Ek2 − Ep

We use the variables θ, ψ,φ as the generalized coordinate. The Lagrangian equation can be derived as:

d
dt (

∂L
∂ θ̇

) −

∂L
∂θ = Fθ

d

dt (
∂L
∂ ψ̇

) −
∂L
∂ψ

= Fψ

d

dt (
∂L
∂ φ̇

) −
∂L
∂φ

= Fφ

Expand the equations ()-(), we can derive the following equations, the whole derivation is in the Appendix:

((2m + M)R

2 + 2Jw + 2n

2

Jm)θ̈+ (MLRcosψ − 2n
2

Jm)ψ̈− MLRsinψ ψ̇ ²

−((2m + M)R

2θ + MLRsinψ)φ̇² = Fθ

(ML

2 + Jψ + 2n

2

Jm)ψ̈+ (−2n
2

Jm + MLRcosψ)θ̈− MgLsinψ

−(MLRθ + ML

2

sinψ)φ̇²
cosψ = Fψ
(

mW²
2

+

W²
2R²

(Jw + n

2
Jm) + Jφ + 2MLRθsinψ + (2m + M)R

2θ

2)φ̈+ 2(2m + M)R
2θθ̇φ̇

+ 2ML

2

sinψcosψ ψ̇φ̇ + 2MLRφ̇(θ̇sinψ + cosψ θψ̇ ) = Fφ

Considering the rolling friction between motor and wheel as well as the friction between wheel and floor, the generalized force are:

Fl = nKt

il + fm(ψ̇ − θl

̇ ) − fwθl

̇

Fr = nKt

ir + fm(ψ̇ − θr

̇ ) − fwθr

̇

10 / 18

Fψ = −nKt

ir − nKt

il − fm(ψ̇ − θr

̇ ) − fm(ψ̇ − θl

̇ )

Where il,r
is DC motor current.

Since the input of our system is voltage of DC motor, in the above equations, we cannot used current il,r directly. Therefore, we have to derive the relationship between current il,r and voltage νl,r
. From DC motor model, The applied voltage equals the voltage drop across the coil resistance, R, and the inductor, L, plus the back-EMF[5], which is as follows:[4]:

νl,r = il,rRm + Lm

dil,r
dt + Kb(ψ̇ − θl,r

̇ )

Where, Rm:DC motor resistance, Lm:DC motor inductance.

For the steady-state torque-speed relationship, Lmhas no effect, so Lmterm is negligible and is approximated as zero. Therefore, rewrite equation() as:

il,r =

νl,r − Kb(ψ̇ − θl,r

̇ )
Rm

When substitute the equation() to equations()-(), the generalized force can be expressed as the function of voltage:

Fθ =

α
2

(νl + νr

) − (β + fw)θ̇ + βψ̇

Fψ = −α(νl + νr

) + 2βθ̇ − 2βψ̇

Fφ =

R
W

α(νl − νr

) − (β + fw)φ̇

Where, α =

nKt
Rm

, β =

nKtKb
Rm

+ fm

### 2.2.3 State equation linearization

So far, we’ve had all the equations we need. At the balance point, when the body angle ψ changes at about ±5

°
, equation() can be linearized. In this case, ψ approximates to be 0, meaning that sin ψ ≈ 0, cos ψ ≈ 1, and ψ̇² ≈ 0. The linearized Lagrangian equations() can be rewritten as follows:

((2m + M)R

2 + 2Jw + 2n

2

Jm)θ̈+ (MLRcosψ − 2n
2

Jm)ψ̈ = Fθ

(ML² + Jψ + 2n

2

Jm)ψ̈+ (MLR − 2n
2

Jm)θ̈− MgLψ = Fψ
(

mW²
2

+

W²
2R²

(Jw + n

2

Jm) + Jφ)φ̈= Fφ

Now, we can combine the equ()-() and the equations()-(), and rewrite these equations in matrix form:
{
E [

θ̈
ψ̈

] + F [

θ̇
ψ̇

] + G [

θ
ψ

] = H [

νl
νr

]

Iφ̈+ Jφ̇ = K(νl − νr
)

Where,

11 / 18

E = [
(2m + M)R

2 + 2Jw + 2n

2
Jm | MLRcosψ − 2n
| 2
Jm
MLR − 2n

2

Jm | ML² + Jψ + 2n
| 2
Jm

]

F = [

β + fw | −β
−2β | 2β

],G = [

0 0
0 −MgL

], H = [

α/2 α/2
−α −α

]

I =

mW²
2

+

W²
2R²

(Jw + n

2
Jm) + Jφ

J = β + fw

K =

R
W

α

Now, we can consider x1 = [θ ψ θ̇ ψ̇]

T

, x2 = [φ φ̇]as the state, u = [νl νr] T as input, we can rewrite
equations() as state space equations form:

x1̇ = A1x1 + B1u

x2̇ = A2x2 + B2u

The state space realization:

A1 = [

0 0
0 0

1 0
0 1
0 A1(3,2)
0 A1(4,2)

A1(3,3) A1(3,4)
A1(4,3) A1(4,4)

],B1 = [

0 0
0 0
B1(3) B1(3)
B1(4) B1(4)

]

A2 = [

0 1
0 −J/I

],B2 = [

0 0
−K/I K/I

]

Where, in the MATLAB:

det(E) = E(1,1)E(1,2) − E(1,2)

2

A1

(3,2) = −MgLE(1,2)/det(E)

A1

(4,2) = MgLE(1,1)/det(E)

A1

(3,3) = −

(β + fw)E(2,2) + 2βE(1,2)
det(E)

A1

(4,3) =

(β + fw)E(1,2) + 2βE(1,1)
det(E)

A1

(3,4) =

β(E(2,2) + 2E(1,2))
det(E)

A1

(4,4) = −

β(E(1,2) + 2E(1,1))
det(E)

B1

(3) =

α(E(2,2)/2 + E(1,2))
det(E)


12 / 18

B1

(4) = −

α(E(1,2)/2 + E(1,1))
det(E)

### 3 CONTROL SYSTEM DESIGN

### 3.1 Control System Theory

### 3.1.1 Input & Output

A. Balance Mode

Input :ν = [νl νr] T

Output: x = [θ ψ θ̇ ψ̇]

T

B. Four-wheeled modes

Input: u = [flag Km Ks

]

Output: x = [Mo1234 Ser1234]

### 3.1.2 Stability

(not yet finish)

### 3.2 Controller design

### 3.2.1 Equivalent system for balance mode

Figure 3.2-1

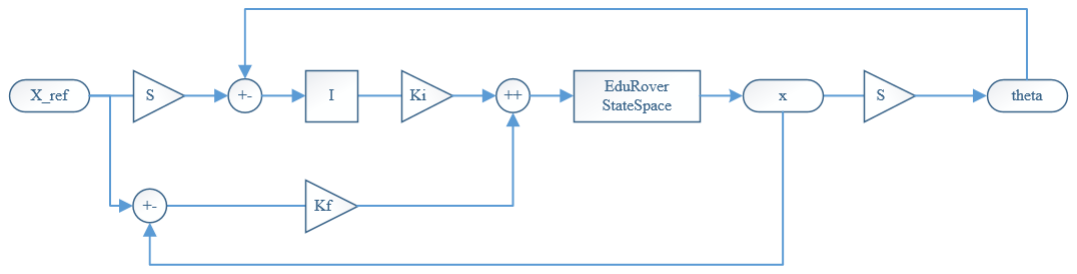
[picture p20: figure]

13 / 18

Figure 3.2-2

### 3.2.2 Simulation

A. Balance Mode

The EduRover balance mode can only be activated when it faces the wall. In the simulation, we only consider the small angle approximation, which is around 5

°
. We can set the initial condition: ψ = 5

°
. The simulation runs in
Simulink. The result is as follows.


14 / 18

Figure 3.2-1

B. Four-wheeled driving mode

In the four-wheeled driving mode, four situation has to be consider: (a) Spinning mode, (b) Normal-car mode, (c) Quarter-turn mode, (d) Sidling mode. To switch from different modes, we have set up a servo logic for these four different modes.

For manual control, we want to minimize the number of inputs as much as possible. The figure 3.2-2 shows that the servo logics in Simulink. In this servo logics, the flag constant controls the logics switching between different modes. Flag(1): Spinning Mode, flag(2): Normal Car Mode, flag(3): Quarter Turn Mode, flag(4): Sidling Mode.

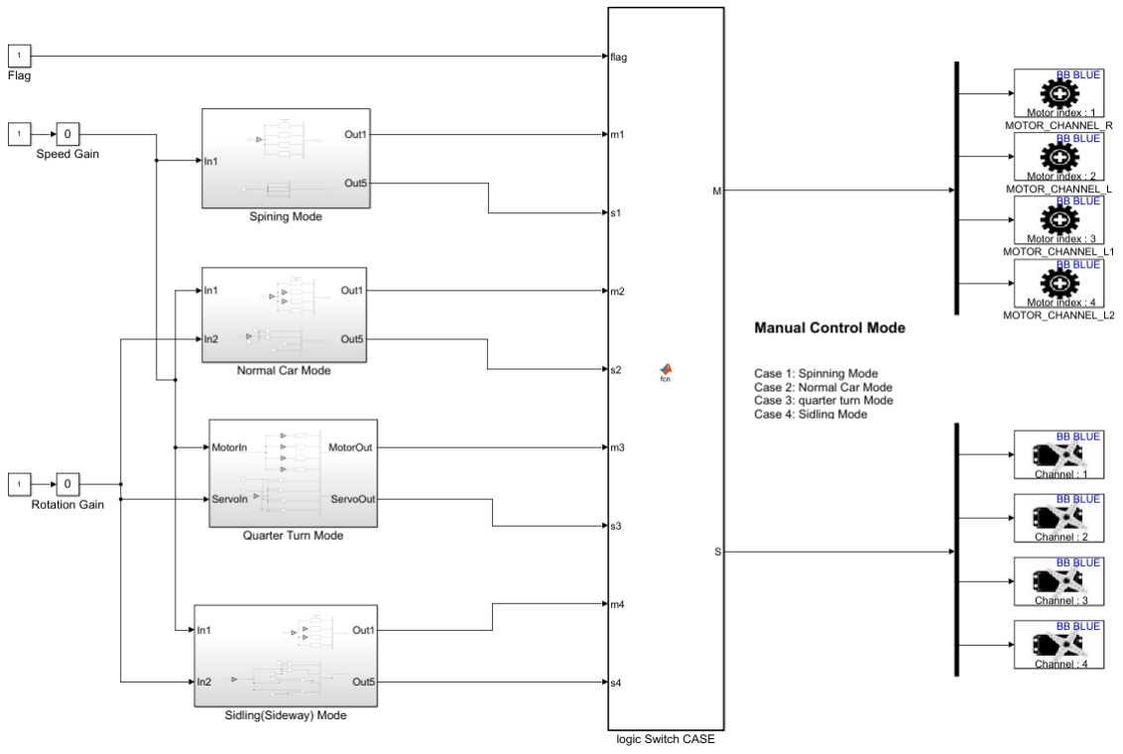
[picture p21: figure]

Figure 3.2-2 Servo logics
3.2.3 Real-world Experiment
A. Balance Mode

(not yet finish)

B. Four-wheeled driving mode

We can use the controller designed in Simulink to control the EduRover in real-time in real-world. The following video links can show you how it performs:
(1) https://github.com/zhz503/Beaglebone-project-EduRover-V2/blob/master/RW%20Simulink%20Control%20and%20Sensing/ManualControl.mp4 (https://github.com/zhz503/Beaglebone-project-EduRover-V2/blob/master/RW%20Simulink%20Control%20and%20Sensing/ManualControl.mp4)
(2) https://github.com/zhz503/Beaglebone-project-EduRover-V2/blob/master/RW%20Simulink%20Control%20and%20Sensing/logics%20switch.MP4 (https://github.com/zhz503/Beaglebone-project-EduRover-V2/blob/master/RW%20Simulink%20Control%20and%20Sensing/logics%20switch.MP4)

### 4 HIGHER LEVEL APPLICATION DESIGN

EduRover is a very decent platform for developer to do higher level application design. There are many applications right now.
In this report, I only list some of the on-going applications:
(1) Way points following based on Motion Capture system
(2) Path planning algorithm based on Motion Capture system
(3) Feature recognition based on web cam on board
(4) ORB-SLAM based on RGBD camera

### 4.1 Way points following based on Motion Capture system

### 4.1.1 Closed loop feedback control

(not yet finish)

### 4.1.2 Motion Capture System

In this project, the motion capture system we used is VICON system. According to the description [5], Vicon are the premier solution for UAV and Robotic studies because we understand what is important; A highly accurate system that provides low latency data that is easy to use. With our turnkey approach and easy to access our DataStream (via TCP, UDP, etc.) users can easily integrate accurate Vicon data into virtually any control system.

### 4.1.3 PID Control Algorithm

This PID control algorithm is designed by Dominique Meyer, which is available in the Github: https://github.com/zhz503/Beaglebone-project-EduRover-V2/tree/master/way_points%20following

### 4.2 Path planning Algorithm on board

### 4.2.1 Workflow


Figure 4-1

APPENDIX A TABLE 1-3 SERVO MOTOR PROPERTIES

Table 1-3 Servo Motor Properties

Product | Seller | Link | No-Load Speed @ 4.8V | Price | Qty | Price/U
| | | (sec/60°) | | | nit
HS-45HB | ServoCity | https://www.servocity.com/hs-45hb-servo | 0.14 | $15.99 | 1 | $15.99
RB-Fit-03 | RobotSho p | https://www.robotshop.com/en/9g-micro- servo-motor-4-8v.html#Supplier-Product- Code (https://www.robotshop.com/en/9g-micro-servo-motor-4-8v.html#Supplier-Product-Code) | 0.12 | $3.56 | 1 | $3.56

Miuzei
SG90 | Amazon

https://www.amazon.com/Micro-Helicopter-Airplane-Remote-Control/dp/B072V529YD?ref_=fsclp_pl_dp_1&th=1 (https://www.amazon.com/Micro-Helicopter-Airplane-Remote-Control/dp/B072V529YD)

0.09 | $17.99 | 10 | $1.80

Seamuing
MG90S | Amazon

https://www.amazon.com/dp/B07F7VJQL5/ref=psdc_2234131011_t2_B072V529YD?th=1 (https://www.amazon.com/dp/B07F7VJQL5/ref=psdc_2234131011_t2_B072V529YD?th=1)

0.11 | $20.99 | 6 | $3.50

SG90
Micro
Servo

Amazon

https://www.amazon.com/dp/B07F2XDZZ7/ref=psdc_2234131011_t2_B072V529YD?th=1 (https://www.amazon.com/dp/B07F2XDZZ7/ref=psdc_2234131011_t2_B072V529YD?th=1)

0.1 | $19.99 | 10 | $2.00

APPENDIX B THE DERIVATION OF LAGRANGIAN EQUATIONS
{

xl = Rθcosφ − Wsinφ/2
xr = Rθcosφ + Wsinφ/2
xb = Rθcosφ + L sin ψ cosφ

⇒ {
xl

̇ = Rθ̇cosφ − Rθsinφ φ̇ − Wφ̇cosφ/2 xr

̇ = Rθ̇cosφ − Rθsinφ φ̇ + Wφ̇cosφ/2 xḃ = Rθ̇cosφ − Rθsinφ φ̇ + Lψ̇ cos ψ cosφ − Lφ̇ sin ψ sinφ

xl

̇

2 + xr
̇

2 = 2(Rθ̇cosφ − Rθsinφ φ̇)

2
+ W²φ²̇ cos² φ /2
{

yl = Rθsinφ + Wcosφ/2
yr = Rθsinφ − Wcosφ/2
yb = Rθsinφ + L sin ψ sinφ

⇒ {
yl

̇ = Rθ̇sinφ + Rθcosφ φ̇ − Wφ̇sinφ/2 yr

̇ = Rθ̇sinφ + Rθcosφ φ̇ + Wφ̇sinφ/2 yḃ = Rθ̇sinφ + Rθcosφ φ̇ + Lψ̇ cos ψ sinφ + Lφ̇ sin ψ cosφ

yl

̇

2 + yr
̇

2 = 2(Rθ̇sinφ + Rθcosφ φ̇)

2
+ W²φ²̇ sin² φ /2
{

zl = R
zr = R
zb = R + L cos ψ

⇒ {
zl

̇ = 0
zr

̇ = 0
zḃ = −Lψ̇sinψ

Ek1 =

1
2

m(xl
̇

2 + yl
̇

2 + zl
̇

2
) +

1
2

m(xr
̇

2 + yr
̇

2 + zr
̇

2
) +

1
2

M(xḃ

2 + yḃ

2 + zḃ

2
) =?
{
θ =

1
2

(θl + θr)

φ =

R
W

(θr − θl)

⇒ {
θl = θ −

W
2R

φ

θr = θ +

W
2R

φ

⇒ {
θl

̇ = θ̇ −

W
2R

φ̇

θr

̇ = θ̇ +

W
2R

φ̇

{

(θl

̇ − ψ̇)

2

= (θ̇ −

W
2R

φ̇ − ψ̇)

2

(θr

̇ − ψ̇)

2 = (θ̇ +

W
2R

φ̇ − ψ̇)

2 ⇒ (θl

̇ − ψ̇)

2
+ (θr

̇ − ψ̇)

2 = 2(θ̇ − ψ̇)

2

+ (

W
2R

φ̇)

2

Ek2 =

1
2

Jwθl

̇

2
+

1
2

Jwθr

̇

2
+

1
2

Jψψ̇² +

1
2

Jφφ̇² +

1
2

n

2
Jm(θl

̇ − ψ̇)
2 +

1
2

n

2
Jm(θr

̇ − ψ̇)
2 =?

Ep = mgzl + mgzr + Mgzb = 2mgR + Mg(R + L cos ψ)

L = Ek1 + Ek2 − Ep =?

∂L
∂ θ̇

=

1
2

((2m + M)R
2

(2θ̇) + MLRψ̇cosψ) + 2Jwθ̇ + 2n
2

Jm(θ̇ − ψ̇)

∂L
∂θ =?

d
dt (

∂L
∂ θ̇

) =?

∂L
∂ ψ̇

=?

∂L
∂ψ

= ？

d

dt (
∂L
∂ ψ̇

) = ？

∂L
∂ φ̇

= ？

∂L
∂φ

= ？

d

dt (
∂L
∂ φ̇

) = ？

{

((2m + M)R

2 + 2Jw + 2n

2

Jm)θ̈+ (MLRcosψ − 2n
2

Jm)ψ̈− MLRsinψ ψ̇ ² − ((2m + M)R

2θ + MLRsinψ)φ̇² = Fθ
(ML

2 + Jψ + 2n

2

Jm)ψ̈+ (−2n
2

Jm + MLRcosψ)θ̈− MgLsinψ − (MLRθ + ML
2

sinψ)φ̇²
cosψ = Fψ
(

mW²
2

+

W²
2R²

(Jw + n

2
Jm) + Jφ + 2MLRθsinψ + (2m + M)R

2θ

2)φ̈+ 2(2m + M)R
2θθ̇φ̇ + 2ML
2

sinψcosψ ψ̇φ̇ + 2MLRφ̇(θ̇sinψ + cosψ θψ̇ ) = Fφ

REFERENCE

[1] https://www.servocity.com/270-rpm-micro-gear-motor-w-encoder
[2] NXTway-GS Model-Based Design, http://www.pages.drexel.edu/~dml46/Tutorials/BalancingBot/files/NXTway-GS%20Model-Based_Design.pdf
[3] UCSD ECE motion and observation model, https://natanaso.github.io/ece276a/ref/ECE276A_8_MotionObservationModels.pdf
[4] https://www.motioncontroltips.com/faq-whats-relationship-voltage-dc-motor-output-speed/
[5] https://www.vicon.com/motion-capture/engineering

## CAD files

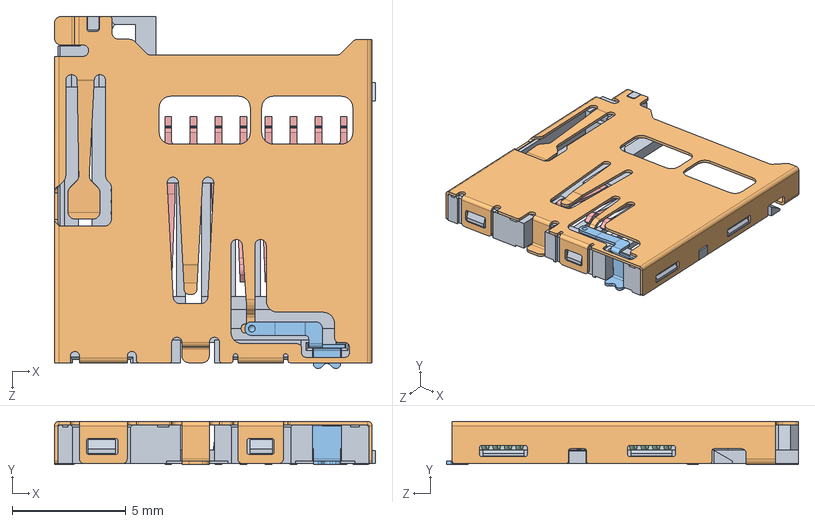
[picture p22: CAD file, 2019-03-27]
Edu Rover Solidworks Version2/BBB Subassembly/Micro sd slot/microSD_Connector.SLDASM
14.1 x 1.90 x 15.4 mm
microSD_Body
microSD_Cover
microSD_Card_Detect
microSD_Pin x 8

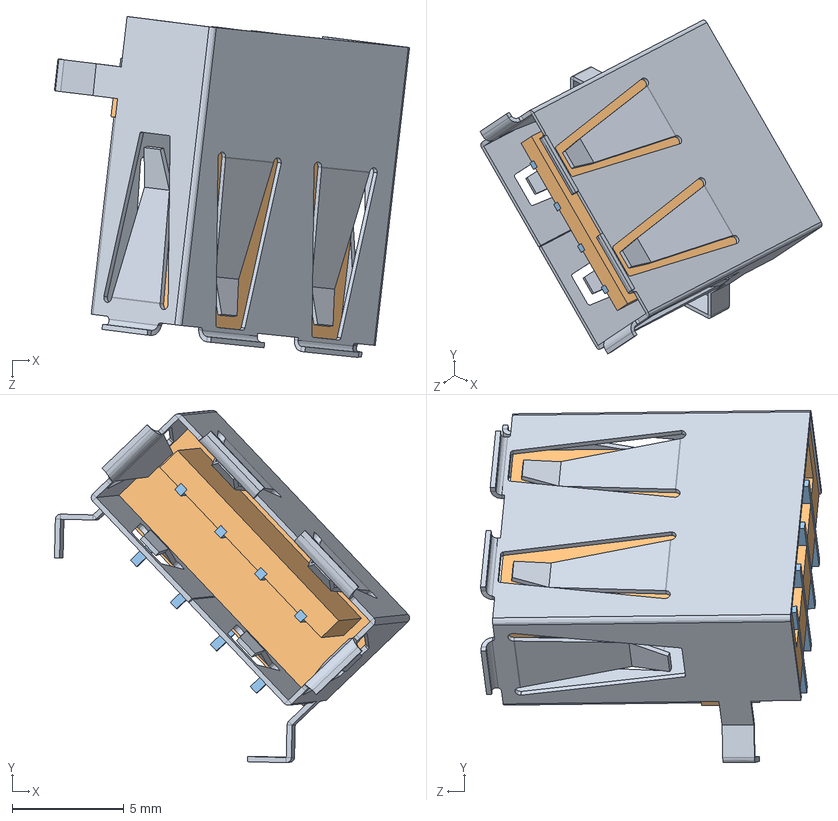
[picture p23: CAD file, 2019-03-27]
Edu Rover Solidworks Version2/BBB Subassembly/USB-A/Usb A.SLDASM
15.9 x 15.7 x 15.2 mm
Usb
plas
conn x 4

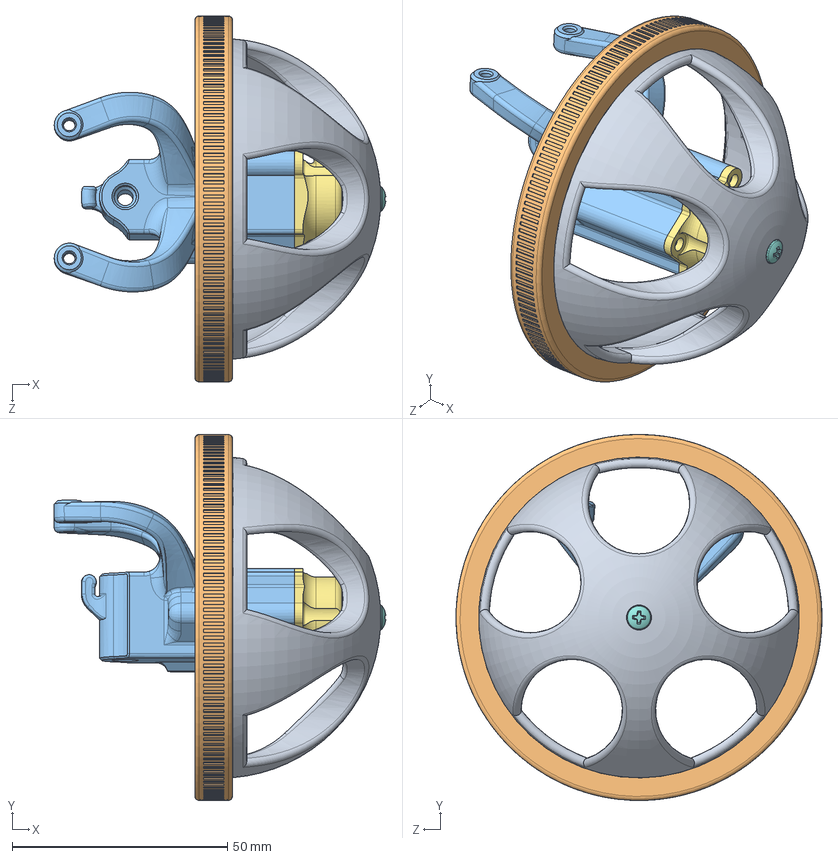
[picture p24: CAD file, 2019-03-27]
Edu Rover Solidworks Version2/Corner Subassembly/Assem_wheel00.SLDASM
77.0 x 85.0 x 85.0 mm
SD-207 EduRover Wheel00
Pololu 90mm Tire
SD-209 Knuckle
newmotor
spline adapter
WW bearing
SD-204 Wheel Bearing Retainer
4-40 .375in BHCS McMaster 91772A108

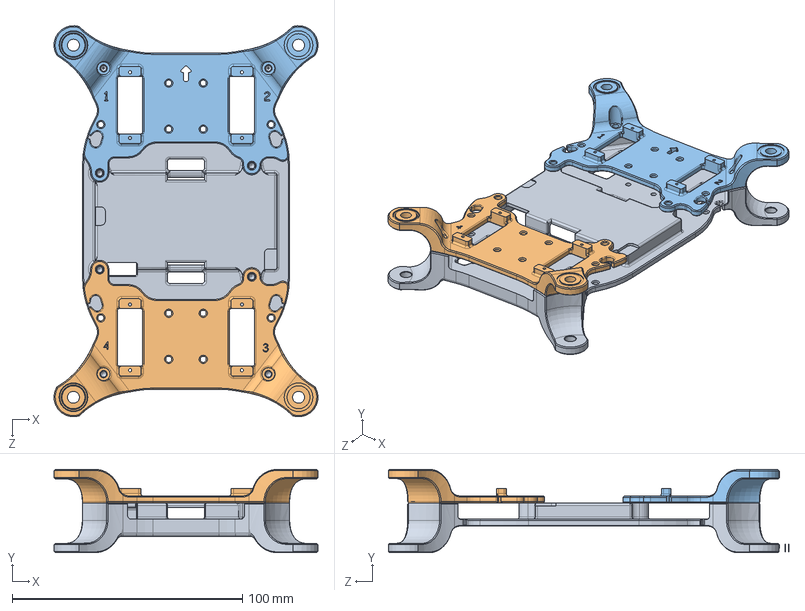
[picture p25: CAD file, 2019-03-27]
Edu Rover Solidworks Version2/Chassis Subassembly/chassis subassembly_new.SLDASM
114.7 x 36.1 x 174.0 mm
SD-202 Chassis Bottom_new
SD-201 Chassis Back_new
SD-201 Chassis Front_new

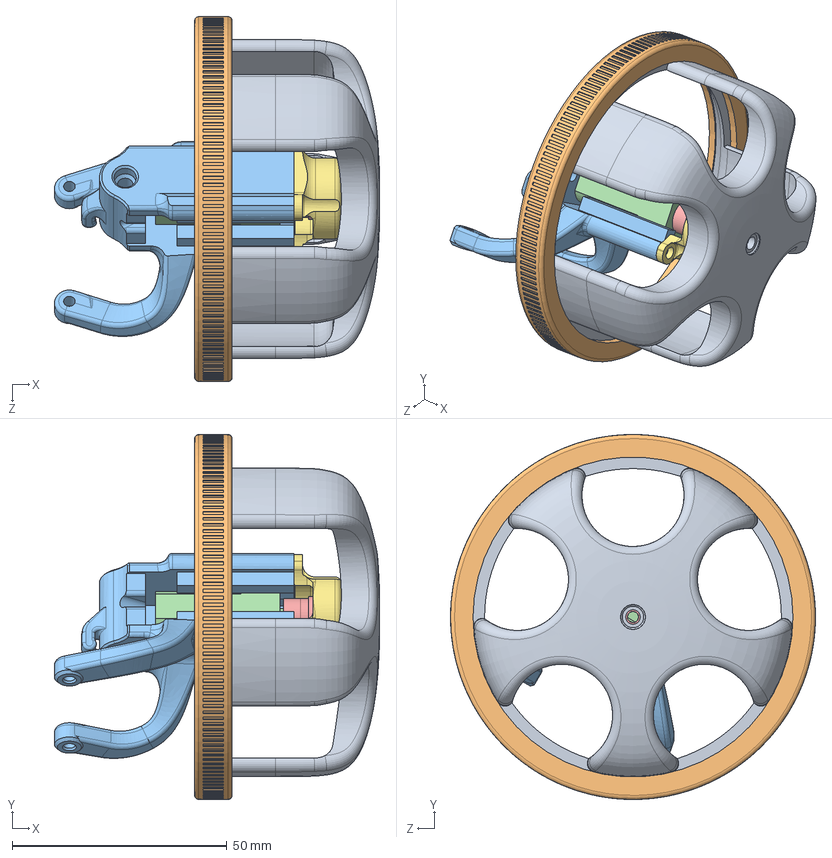
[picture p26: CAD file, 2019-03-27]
Edu Rover Solidworks Version2/Corner Subassembly/Assem_wheel.SLDASM
75.7 x 85.0 x 85.0 mm
SD-207 EduRover Wheel
Pololu 90mm Tire
SD-209 Knuckle
newmotor
spline adapter
WW bearing
SD-204 Wheel Bearing Retainer

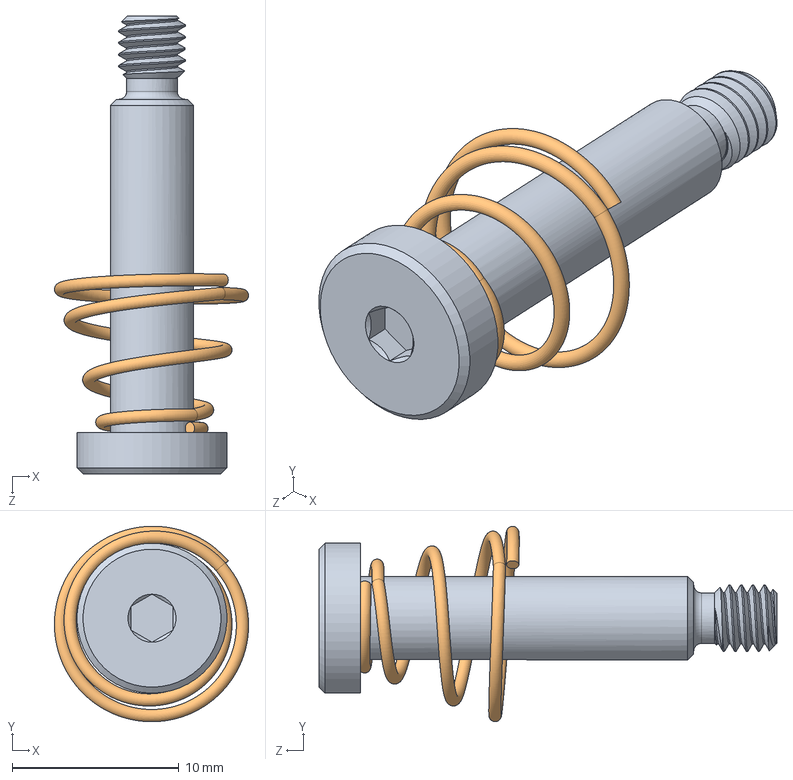
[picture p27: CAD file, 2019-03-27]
Edu Rover Solidworks Version2/Hardware/Assem_3.SLDASM
11.7 x 11.7 x 27.5 mm
M4x20 Low Profile Shoulder Screw 90323A328
0.375in conical spring 1692K510

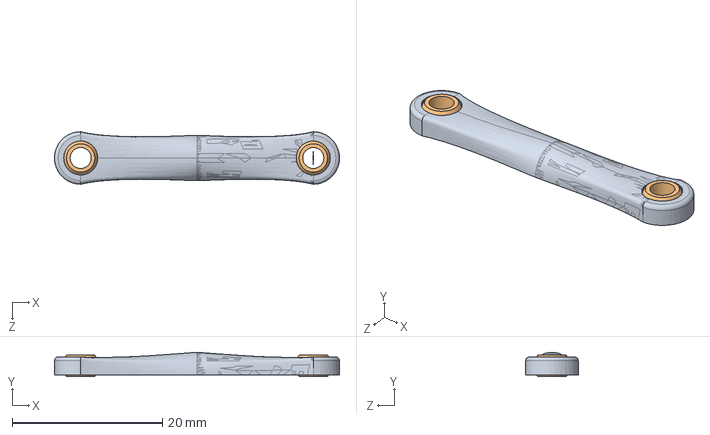
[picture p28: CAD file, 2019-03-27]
Edu Rover Solidworks Version2/Servo Subassembly/ball_linkage_new.SLDASM
38.0 x 3.24 x 7.00 mm
SD-205 Steering Linkage_new
ball linkage ball 4 40 x 2

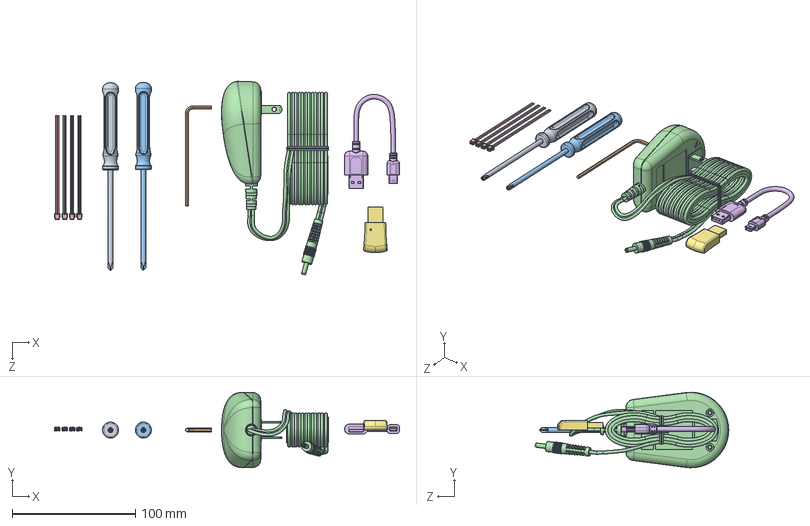
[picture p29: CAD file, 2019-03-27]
Edu Rover Solidworks Version2/accessories/accessories.SLDASM
280.1 x 61.3 x 157.1 mm
Philips Screwdriver P2
2.5mm allan key
Philips Screwdriver P0
12v 1A DC power supply
JST ZH 2-Pin Pigtail x 4
mini usb cable
Bluetooth Dongle

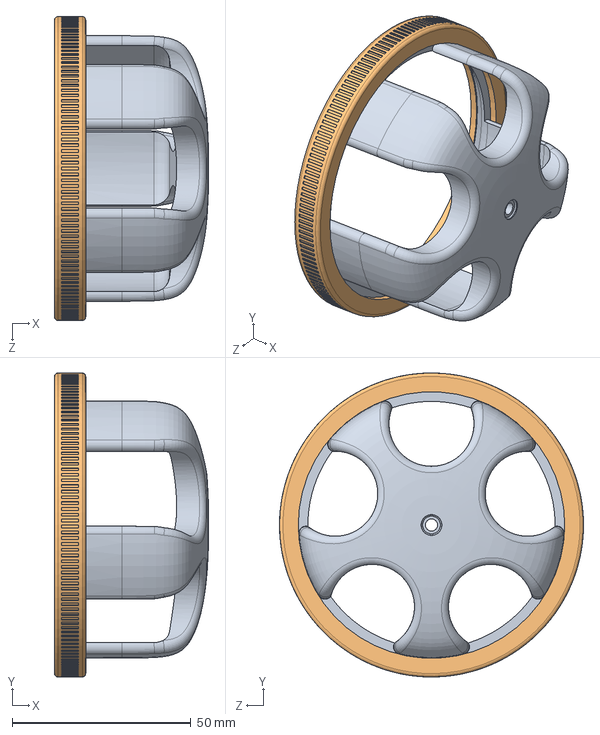
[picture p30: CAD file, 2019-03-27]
Edu Rover Solidworks Version2/Corner Subassembly/Assem_wheel01.SLDASM
43.1 x 85.0 x 85.0 mm
SD-207 EduRover Wheel
Pololu 90mm Tire

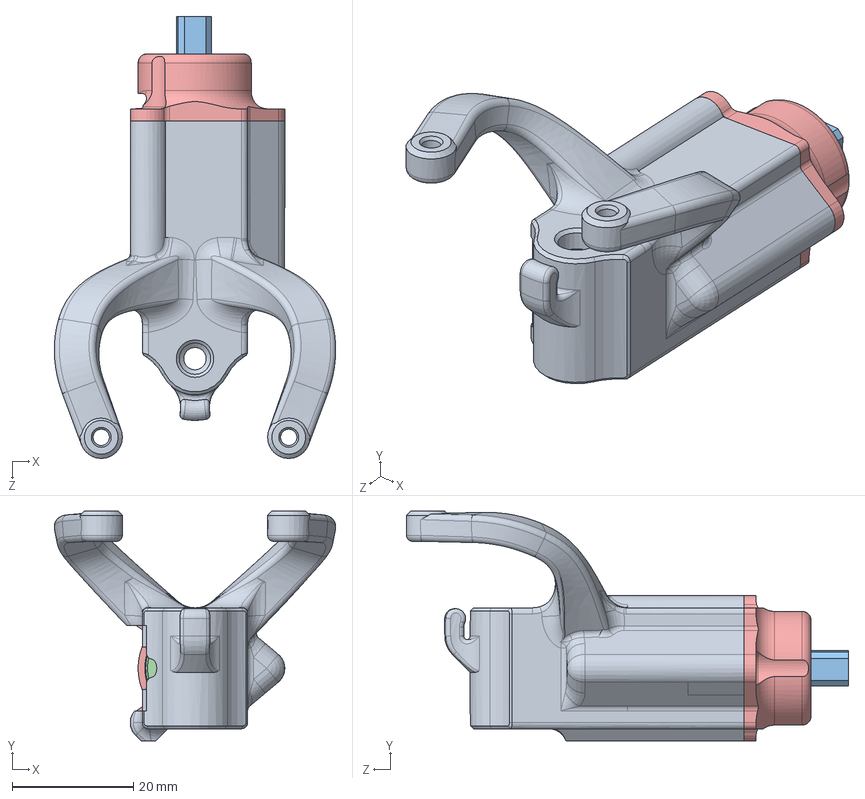
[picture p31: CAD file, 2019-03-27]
Edu Rover Solidworks Version2/Corner Subassembly/Assem_new.SLDASM
46.5 x 38.0 x 73.0 mm
SD-209 Knuckle
newmotor
spline adapter
WW bearing
SD-204 Wheel Bearing Retainer

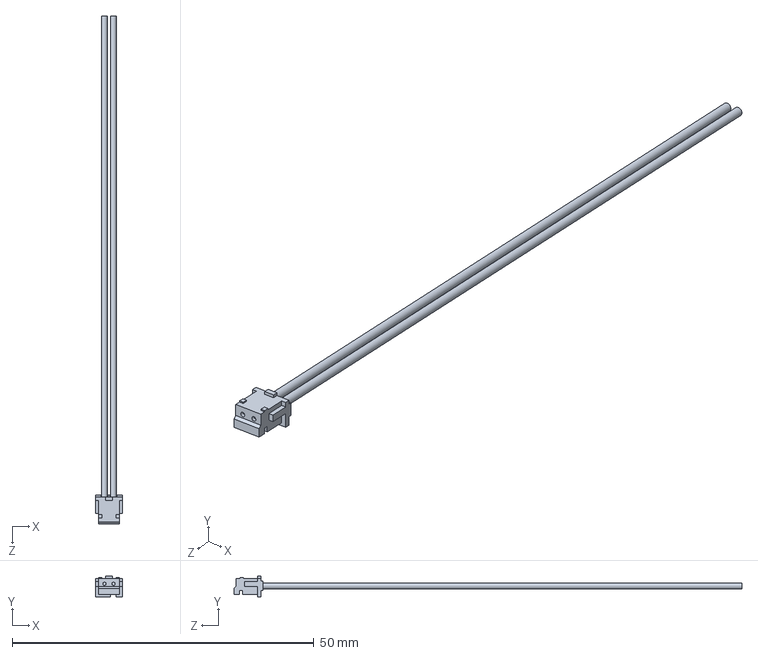
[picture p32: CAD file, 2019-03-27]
Edu Rover Solidworks Version2/accessories/JST ZH 2-Pin Pigtail.SLDPRT
4.50 x 3.40 x 84.2 mm

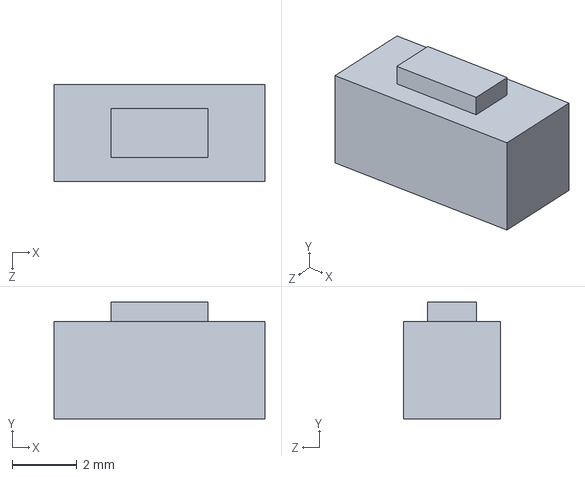
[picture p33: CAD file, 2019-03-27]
Edu Rover Solidworks Version2/BBB Subassembly/Beaglebone Component/buttom.SLDPRT
6.50 x 3.60 x 3.00 mm

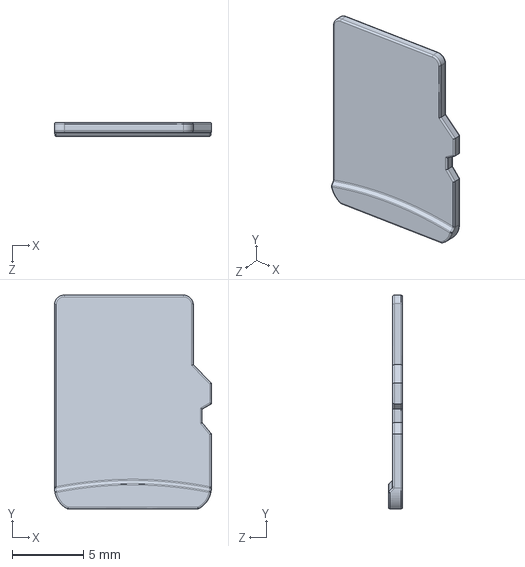
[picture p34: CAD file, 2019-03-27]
Edu Rover Solidworks Version2/BBB Subassembly/Micro sd slot/Micro SD Card.SLDPRT
11.0 x 15.0 x 1.00 mm

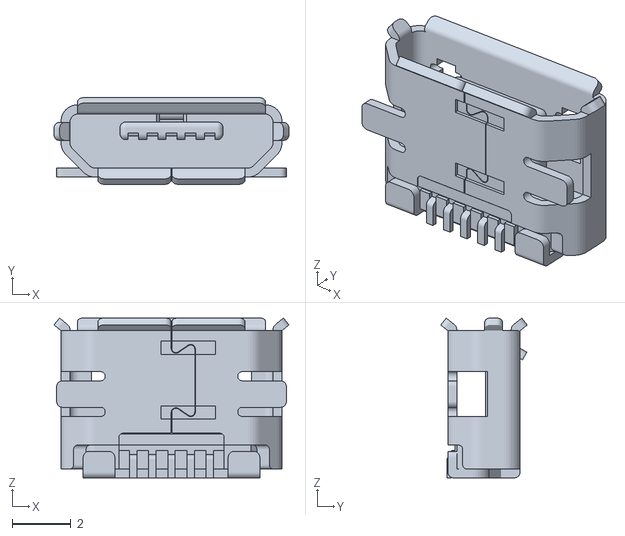
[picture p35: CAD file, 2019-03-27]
Edu Rover Solidworks Version2/BBB Subassembly/Micro_usb/micro_usb_47346-0001.STL
7.98 x 2.94 x 5.43

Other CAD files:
Edu Rover Solidworks Version2/BBB Subassembly/USB-A/conn.SLDPRT
Edu Rover Solidworks Version2/Chassis Subassembly/SD-201 Chassis Back_new.SLDPRT
Edu Rover Solidworks Version2/Corner Subassembly/SD-207 EduRover Wheel00.SLDPRT
Edu Rover Solidworks Version2/Servo Subassembly/SD-206 Servo Horn.SLDPRT
Edu Rover Solidworks Version2/BBB Subassembly/Beaglebone Component/BeagleBoneBlue_board.SLDPRT
Edu Rover Solidworks Version2/BBB Subassembly/Beaglebone Component/SD-105 DC Plug.SLDPRT
Edu Rover Solidworks Version2/BBB Subassembly/Beaglebone Component/antennas.SLDPRT
Edu Rover Solidworks Version2/BBB Subassembly/Micro sd slot/microSD_Body.SLDPRT
Edu Rover Solidworks Version2/BBB Subassembly/Micro sd slot/microSD_Card_Detect.SLDPRT
Edu Rover Solidworks Version2/BBB Subassembly/Micro sd slot/microSD_Cover.SLDPRT
Edu Rover Solidworks Version2/BBB Subassembly/Micro sd slot/microSD_Pin.SLDPRT
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

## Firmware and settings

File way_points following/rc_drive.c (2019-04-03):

/**
 * @file rc_drive.c
 *
 * This is meant to be a program to control the edurover (available at
 * https://github.com/StrawsonDesign/EduRover). Code structure built from
 * rc_balance.c in Examples of Robotics Cape Library Full Credit to James
 * Strawson for the Robotics Cape Library and assistance to create this code.
 * Last edited by Dominique Meyer on 06/08/2018 for CSE291D@UCSD
 */

#include <stdio.h>
#include <unistd.h> // for isatty()
#include <stdlib.h> // for strtof()
#include <getopt.h>
#include <signal.h>
#include <math.h> // for M_PI
#include <roboticscape.h> // includes ALL robotics cape subsystems
#include <rc/mavlink_udp.h>
#include <rc/mavlink_udp_helpers.h>

#include "drive_types.h"
#include "rc_drive_defs.h" // includes all parameters defining the edurover





/////////////////////////// FUNCTION DECLARATIONS //////////////////////////////

void controller();			///< mpu ISR feedback controller
void* setpoint_manager(void* ptr);	///< setpoint manager background thread
void* battery_checker(void* ptr);	///< background  batterythread
void* printf_loop(void* ptr);		///< background thread

int zero_out_controller();
int disarm_controller();
int arm_controller();
int wait_for_starting_condition();
void on_pause_press();
void callback_func_any();


/////////////////////////// GLOBAL VARIABLES ////////////////////////////////////

core_state_t cstate;
setpoint_t setpoint;
rc_filter_t D1;		///< velocity PID controller
rc_mpu_data_t mpu_data;
task_t task;

const char* dest_ip;
uint8_t my_sys_id;
uint16_t port;
FILE *fp;


/////////////////////////////// MAIN LOOP ////////////////////////////////////


/**
 * @brief Initialize the filters, mpu, threads, & wait until shut down
 *
 * @return     0 on success, -1 on failure
 */
int main(int argc, char *argv[])
{
	pthread_t setpoint_thread = 0;
	pthread_t battery_thread = 0;
	pthread_t printf_thread = 0;

	// parse arguments
	opterr = 0;

	// load in task waypoints
	#include "hw2_task.h"

///////////////////// SIGNAL HANDLER/ PID FILE /////////////////////////////////

	// make sure another instance isn't running
	// return value -3 means a root process is running and we need more
	// privileges to stop it.
	if(rc_kill_existing_process(2.0)==-3) return -1;
	// start signal handler so we can exit cleanly
	if(rc_enable_signal_handler()==-1){
		fprintf(stderr,"ERROR: failed to start signal handler\n");
		return -1;
	}
	// make PID file to indicate project is running
	rc_make_pid_file();

//////////// INIT BASIC HARDWARE, MOTORS, BUTTONS, LEDS ////////////////////////

	// initialize buttons
	if(rc_button_init(RC_BTN_PIN_PAUSE, RC_BTN_POLARITY_NORM_HIGH,
			RC_BTN_DEBOUNCE_DEFAULT_US)){
		fprintf(stderr,"ERROR: failed to initialize pause button\n");
		return -1;
	}
	if(rc_button_init(RC_BTN_PIN_MODE, RC_BTN_POLARITY_NORM_HIGH,
			RC_BTN_DEBOUNCE_DEFAULT_US)){
		fprintf(stderr,"ERROR: failed to initialize mode button\n");
		return -1;
	}
	// Assign functions to be called when button events occur
	rc_button_set_callbacks(RC_BTN_PIN_PAUSE,on_pause_press,NULL);

	// initialize enocders
	if(rc_encoder_eqep_init()==-1){
		fprintf(stderr,"ERROR: failed to initialize eqep encoders\n");
		return -1;
	}
	if(rc_encoder_pru_init()==-1){
		fprintf(stderr,"ERROR: failed to initialize pru encoder\n");
		return -1;
	}

	// initialize motors
	if(rc_motor_init()==-1){
		fprintf(stderr,"ERROR: failed to initialize motors\n");
		return -1;
	}
	rc_motor_standby(0); // start with motors not in standby

	// initialize adc
	if(rc_adc_init()==-1){
		fprintf(stderr, "failed to initialize adc\n");
		return -1;
	}


	// start with RED lef on, turn off after init
	if(rc_led_set(RC_LED_GREEN, 0)==-1){
		fprintf(stderr, "ERROR in rc_balance, failed to set RC_LED_GREEN\n");
		return -1;
	}
	if(rc_led_set(RC_LED_RED, 1)==-1){
		fprintf(stderr, "ERROR in rc_balance, failed to set RC_LED_RED\n");
		return -1;
	}


////////////////////////////////    MPU/DMP    /////////////////////////////////

	// set up mpu configuration
	rc_mpu_config_t mpu_config = rc_mpu_default_config();
	mpu_config.dmp_sample_rate = SAMPLE_RATE_HZ;
	//mpu_config.enable_magnetometer = 1;

	//run calibration routine for gyro
	rc_mpu_calibrate_gyro_routine(mpu_config);

	// make sure setpoint starts at normal values
	setpoint.arm_state = DISARMED;
	D1 = rc_filter_empty();

	// set up D1 Velocity Controller
	if(rc_filter_pid(&D1, D1_KP, D1_KI, D1_KD, 4*DT, DT)){
		fprintf(stderr,"ERROR in rc_drive, failed to make velocity PID controller\n");
		return -1;
	}
	rc_filter_enable_saturation(&D1, -1.0, 1.0);

//////////////////////////////// START THREADS /////////////////////////////////

	// start a thread to slowly sample battery
	if(rc_pthread_create(&battery_thread, battery_checker, (void*) NULL, SCHED_OTHER, 0)){
		fprintf(stderr, "failed to start battery thread\n");
		return -1;
	}
	// wait for the battery thread to make the first read
	while(cstate.vBatt==0 && rc_get_state()!=EXITING) rc_usleep(1000);
	// start printf_thread if running from a terminal
	// if it was started as a background process then don't bother
	if(isatty(fileno(stdout))){
		if(rc_pthread_create(&printf_thread, printf_loop, (void*) NULL, SCHED_OTHER, 0)){
			fprintf(stderr, "failed to start printf thread\n");
			return -1;
		}
	}
	// start mpu
	if(rc_mpu_initialize_dmp(&mpu_data, mpu_config)){
		fprintf(stderr,"ERROR: can't talk to IMU, all hope is lost\n");
		rc_led_blink(RC_LED_RED, 5, 5);
		return -1;
	}
	// start balance stack to control setpoints
	if(rc_pthread_create(&setpoint_thread, setpoint_manager, (void*) NULL, SCHED_OTHER, 0)){
		fprintf(stderr, "failed to start setpoint controller thread\n");
		return -1;
	}
	// this should be the last step in initialization
	// to make sure other setup functions don't interfere
	rc_mpu_set_dmp_callback(&controller);

	// start Mavlink thread

	// set default options before checking options
	dest_ip = MAVLINK_HOST_IP;
	my_sys_id = DEFAULT_SYS_ID;
	port = RC_MAV_DEFAULT_UDP_PORT;

	if(rc_mav_init(my_sys_id, dest_ip, port,RC_MAV_DEFAULT_CONNECTION_TIMEOUT_US)==0){
		rc_mav_set_callback_all(callback_func_any);
		printf("Mavlink initialized\n");
	}
	else{
		return -1;
	}

	// starting file log and assigning pointer.
	fp = fopen("log.txt","w");




//////////////// TELL USER SETUP IS DONE AND TWIDDLE THUMBS ////////////////////

	// start in the RUNNING state, pressing the pause button will swap to
	// the PAUSED state then back again.
	printf("\nHit the MODE button to begin path following\n");
	rc_set_state(RUNNING);

	// chill until something exits the program
	rc_set_state(RUNNING);
	while(rc_get_state()!=EXITING){
		rc_usleep(500000);
	}


////////////////       JOIN THREADS AND CLEAN UP           ////////////////////
	// join threads
	rc_pthread_timed_join(setpoint_thread, NULL, 1.5);
	rc_pthread_timed_join(battery_thread, NULL, 1.5);
	rc_pthread_timed_join(printf_thread, NULL, 1.5);

	// cleanup
	rc_filter_free(&D1);
	rc_mpu_power_off();
	rc_led_set(RC_LED_GREEN, 0);
	rc_led_set(RC_LED_RED, 0);
	rc_led_cleanup();
	rc_encoder_eqep_cleanup();
	rc_encoder_pru_cleanup();
	rc_button_cleanup();		// stop button handlers
	rc_remove_pid_file();		// remove pid file LAST
	return 0;
}


int ar;

////////////////////////// Setpoint Manager ////////////////////////////////////
/**
 * @brief Adjusts the controller setpoint based on user
 * input of waypoint files.
 *
 * @param      ptr   The pointer
 *
 * @return    NULL
 */
void* setpoint_manager(__attribute__ ((unused)) void* ptr)
{

	// make sure waypoint counter starts at 0
	// wait for mpu to settle
	disarm_controller();
	rc_usleep(2500000);
	rc_set_state(RUNNING);
	rc_led_set(RC_LED_RED,0);
	rc_led_set(RC_LED_GREEN,1);

	while(rc_get_state()!=EXITING){

		// nothing to do if paused, go back to beginning of loop
		if(rc_get_state() != RUNNING) continue;
		// if we got here the state is RUNNING, but controller is not
		// necessarily armed. If DISARMED, wait for the user to pick MIP up
		// which will we detected by wait_for_starting_condition()
		if(setpoint.arm_state == DISARMED){
			if(wait_for_starting_condition()==0){
				zero_out_controller();
				arm_controller();
			}
			else continue;
		}

		// if no waypoint reached, set next setpoints
		if(cstate.rho >= WAYPOINT_ACCEPTANCE_RADIUS){
			continue;
		}

		//if reached current waypoint goal, set next waypoint as goal
		if(cstate.rho <= WAYPOINT_ACCEPTANCE_RADIUS){
			if(setpoint.current_waypoint >= NUM_WAYPOINTS){
				fprintf(stderr, "\nRover has Reached Final Waypoint %d \n",setpoint.current_waypoint);
				disarm_controller();
				rc_set_state(PAUSED);
			}
			else{
				fprintf(stderr, "\nRover has Reached Waypoint %d \n",setpoint.current_waypoint);
				setpoint.current_waypoint++;
				setpoint.pos_x = task.waypoints[setpoint.current_waypoint].x;
				setpoint.pos_y = task.waypoints[setpoint.current_waypoint].y;
				setpoint.beta  = task.waypoints[setpoint.current_waypoint].heading;
				rc_usleep(50000000);
				continue;
			}
		}

		// clear out input of old data before waiting for new data
		rc_usleep(1000000/SETPOINT_MANAGER_HZ);

	}
	// if state becomes EXITING the above loop exists and we disarm here
	disarm_controller();
	return NULL;
}

//////////////////////////////// MAIN CONTROLLER ////////////////////////////////////////

/**
 * discrete-time motion controller operated off mpu interrupt Called at
 * SAMPLE_RATE_HZ
 */
void controller()
{
	int i;
	float current_avg_wheel_angle;
	float current_avg_wheel_speed;

	/******************************************************************
	* STATE_ESTIMATION
	* read sensors and compute the state when either ARMED or DISARMED
	******************************************************************/
	// collect encoder positions, right wheel is reversed
	cstate.wheel_angle[1] = (rc_encoder_eqep_read(ENCODER_CHANNEL_FL) * 2.0 * M_PI) \
		/(ENCODER_POLARITY_FL * GEARBOX * ENCODER_RES);
	cstate.wheel_angle[2] = (rc_encoder_eqep_read(ENCODER_CHANNEL_FR) * 2.0 * M_PI) \
		/(ENCODER_POLARITY_FR * GEARBOX * ENCODER_RES);

	current_avg_wheel_angle = (cstate.wheel_angle[1] + cstate.wheel_angle[2])/2.0;
	current_avg_wheel_speed = (current_avg_wheel_angle - cstate.last_avg_wheel_angle)/DT;

	cstate.forward_velocity = current_avg_wheel_speed*WHEEL_RADIUS_M;
	//cstate.heading = mpu_data.compass_heading;
	//cstate.heading_dot = mpu_data.gyro[2]*DEG_TO_RAD-(M_PI/2);

	//cstate.pos_x = cstate.pos_x + cos(cstate.heading)*cstate.forward_velocity*DT;
	//cstate.pos_y = cstate.pos_y + sin(cstate.heading)*cstate.forward_velocity*DT;

	// save last angle
	cstate.last_avg_wheel_angle = current_avg_wheel_angle;

	// distance to next waypoint
	cstate.rho = sqrt (pow((task.waypoints[setpoint.current_waypoint].x - cstate.pos_x),2) + pow((task.waypoints[setpoint.current_waypoint].y - cstate.pos_y),2));
	setpoint.forward_vel = KRHO*cstate.rho;

	if (setpoint.forward_vel < 0.3){
		setpoint.forward_vel = 0.3;
	}
	else if (setpoint.forward_vel > 0.5){
		setpoint.forward_vel = 0.5;
	}



	// angle to waypoint from current pos
	cstate.wp_heading = atan2((task.waypoints[setpoint.current_waypoint].x - cstate.pos_x),(task.waypoints[setpoint.current_waypoint].y - cstate.pos_y));

	cstate.wp_heading = cstate.wp_heading + M_PI;

	if (cstate.wp_heading >= M_PI){
		cstate.wp_heading = cstate.wp_heading - M_PI;
	}
	else if(cstate.wp_heading < M_PI){
		cstate.wp_heading = cstate.wp_heading + M_PI;
	}

	// if (cstate.wp_heading <0.0){
	// 	cstate.wp_heading += M_PI*2;
	// }
	// cstate.alpha = cstate.wp_heading - cstate.heading- M_PI/4;
	// if(cstate.alpha > M_PI){
	// 	cstate.alpha = (cstate.wp_heading - cstate.heading- M_PI/4) - M_PI*2;
	// }

	// if((cstate.wp_heading - cstate.heading) > M_PI*2){
	// 	cstate.alpha = -(cstate.wp_heading + cstate.heading-M_PI/4);
	// }
	// else{
	// 	cstate.alpha = cstate.wp_heading - cstate.heading - M_PI/4;
	// }
	cstate.alpha = cstate.wp_heading - cstate.heading;

	if(cstate.alpha > M_PI){
		cstate.alpha = cstate.alpha - M_PI*2;
	}
	else if(cstate.alpha < - M_PI){
		cstate.alpha = cstate.alpha + M_PI*2;
	}

	/*************************************************************
	* check for various exit conditions AFTER state estimate
	***************************************************************/
	if(rc_get_state()==EXITING){
		rc_motor_standby(0);
		for(i=1;i<5;i++){
			rc_motor_set(i,0.0);
		}

	return;
	}
	// if controller is still ARMED while state is PAUSED, disarm it
	if(rc_get_state()!=RUNNING && setpoint.arm_state==ARMED){
		disarm_controller();
		return;
	}
	// exit if the controller is disarmed
	if(setpoint.arm_state==DISARMED){
		return;
	}

	/*************************************************************
	*steering angle derivation
	***************************************************************/

	// calculate steering angle using Alpha and Beta with some tuning variables

	setpoint.steering_angle = (KA*cstate.alpha + KB*setpoint.beta)/2;

	if(setpoint.steering_angle >= AWD_MAX_STEERING_ANGLE){
		setpoint.steering_angle = AWD_MAX_STEERING_ANGLE;
	}
	else if(setpoint.steering_angle <= -AWD_MAX_STEERING_ANGLE){
		setpoint.steering_angle = -AWD_MAX_STEERING_ANGLE;
	}

	/*************************************************************
	*Ackerman Steering Calculations and Output
	***************************************************************/

	setpoint.icr = (WHEEL_FORWARD_BASELINE/2)/tan(setpoint.steering_angle);
	setpoint.out_steering_angle = atan((WHEEL_FORWARD_BASELINE/2)/(setpoint.icr + WHEEL_SIDE_BASELINE/2));
	setpoint.in_steering_angle = atan((WHEEL_FORWARD_BASELINE/2)/(setpoint.icr - WHEEL_SIDE_BASELINE/2));

	setpoint.out_steering_input = (setpoint.out_steering_angle*WHEEL_PI_INPUT / (M_PI/2));
	setpoint.in_steering_input = (setpoint.in_steering_angle*WHEEL_PI_INPUT / (M_PI/2));



	/**********************************************************
	* velocity PID controller D1
	***********************************************************/
	float new_motor_power; // net power to motors, from -1 to 1
	new_motor_power = rc_filter_march(&D1,setpoint.forward_vel- cstate.forward_velocity);
	//fprintf(stderr, "Set forward %f \n",setpoint.forward_vel);
	//fprintf(stderr, "Speed %f \n",new_motor_power);



	/**********************************************************
	* Send signal to motors and servos
	***********************************************************/


	rc_motor_set(1,new_motor_power*MOTOR_POLARITY_FL);
	cstate.mot_drive[0] = new_motor_power*MOTOR_POLARITY_FL;

	rc_motor_set(2,new_motor_power*MOTOR_POLARITY_FR);
	cstate.mot_drive[1] = new_motor_power*MOTOR_POLARITY_FR;

	rc_motor_set(3,new_motor_power*MOTOR_POLARITY_RR);
	cstate.mot_drive[2] = new_motor_power*MOTOR_POLARITY_RR;

	rc_motor_set(4,new_motor_power*MOTOR_POLARITY_RL);
	cstate.mot_drive[3] = new_motor_power*MOTOR_POLARITY_RL;



	if(setpoint.steering_angle < 0){
		rc_servo_send_pulse_normalized(1, (SERVO_CENTER_FL - WHEEL_STRAIGHT_INPUT + setpoint.in_steering_input));
		cstate.steer_angle[1] = setpoint.in_steering_angle;
		rc_servo_send_pulse_normalized(2, (SERVO_CENTER_FR + WHEEL_STRAIGHT_INPUT + setpoint.out_steering_input));
		cstate.steer_angle[2] = setpoint.out_steering_angle;
		rc_servo_send_pulse_normalized(3, (SERVO_CENTER_RR - WHEEL_STRAIGHT_INPUT - setpoint.out_steering_input));
		cstate.steer_angle[3] = setpoint.out_steering_angle;
		rc_servo_send_pulse_normalized(4, (SERVO_CENTER_RL + WHEEL_STRAIGHT_INPUT - setpoint.in_steering_input));
		cstate.steer_angle[4] = setpoint.in_steering_angle;
	}
	else if(setpoint.steering_angle > 0){
		rc_servo_send_pulse_normalized(1, (SERVO_CENTER_FL - WHEEL_STRAIGHT_INPUT + setpoint.out_steering_input));
		cstate.steer_angle[1] = setpoint.in_steering_angle;
		rc_servo_send_pulse_normalized(2, (SERVO_CENTER_FR + WHEEL_STRAIGHT_INPUT + setpoint.in_steering_input));
		cstate.steer_angle[2] = setpoint.out_steering_angle;
		rc_servo_send_pulse_normalized(3, (SERVO_CENTER_RR - WHEEL_STRAIGHT_INPUT - setpoint.in_steering_input));
		cstate.steer_angle[3] = setpoint.out_steering_angle;
		rc_servo_send_pulse_normalized(4, (SERVO_CENTER_RL + WHEEL_STRAIGHT_INPUT - setpoint.out_steering_input));
		cstate.steer_angle[4] = setpoint.in_steering_angle;
	}
	else if(setpoint.steering_angle == 0){
		rc_servo_send_pulse_normalized(1, (SERVO_CENTER_FL - WHEEL_STRAIGHT_INPUT));
		cstate.steer_angle[1] = 0;
		rc_servo_send_pulse_normalized(2, (SERVO_CENTER_FR + WHEEL_STRAIGHT_INPUT));
		cstate.steer_angle[2] = 0;
		rc_servo_send_pulse_normalized(3, (SERVO_CENTER_RR - WHEEL_STRAIGHT_INPUT));
		cstate.steer_angle[3] = 0;
		rc_servo_send_pulse_normalized(4, (SERVO_CENTER_RL + WHEEL_STRAIGHT_INPUT));
		cstate.steer_angle[4] = 0;

	}




	return;
}



/**
 * Clear the controller's memory and zero out setpoints.
 *
 * @return     { description_of_the_return_value }
 */
int zero_out_controller()
{
	int i;
	rc_filter_reset(&D1);
	// zero out setpoint
	setpoint.pos_x =	0.0;
	setpoint.pos_x_dot =	0.0;
	setpoint.pos_y =	0.0;
	setpoint.pos_y_dot =	0.0;

	setpoint.current_waypoint = 0;

	// zero out state
	cstate.pos_x =		0.0;
	cstate.pos_x_dot =	0.0;
	cstate.pos_y =		0.0;
	cstate.pos_y_dot =	0.0;
	cstate.rho =		0.0;
	cstate.alpha =		0.0;

	for(i=0;i<4;i++){
		cstate.steer_angle[i]=0.0;
		cstate.wheel_angle[i]=0.0;
		cstate.wheel_speed[i]=0.0;
	}

	cstate.last_avg_wheel_angle = 0.0;

	rc_motor_standby(0);
	for(i=1;i<5;i++){
		rc_motor_set(i,0.0);
	}
	return 0;
}

/**
 * disable motors & set the setpoint.core_mode to DISARMED
 *
 * @return     { description_of_the_return_value }
 */
int disarm_controller()
{
	rc_motor_standby(1);

	setpoint.arm_state = DISARMED;
	return 0;
}

/**
 * zero out the controller & encoders. Enable motors & arm the controller.
 *
 * @return     0 on success, -1 on failure
 */
int arm_controller()
{
	rc_encoder_eqep_write(1,0);
	rc_encoder_eqep_write(2,0);
	rc_encoder_eqep_write(3,0);
//	rc_encoder_pru_write(0);
	rc_motor_standby(0);
	rc_servo_init();
	rc_servo_power_rail_en(1);
	setpoint.arm_state = ARMED;
	return 0;
}

/**
 * Wait for MiP to be held upright long enough to begin. Returns
 *
 * @return     0 if successful, -1 if the wait process was interrupted by pause
 *             button or shutdown signal.
 */
int wait_for_starting_condition()
{
	// wait for MiP to be tipped back or forward first
	// exit if state becomes paused or exiting
	while(rc_get_state()==RUNNING){
		rc_usleep(100000);
		// if within range, start counting
		if(rc_button_get_state(RC_BTN_PIN_MODE)==RC_BTN_STATE_RELEASED) continue;
		else return 0;
	}
	return -1;
}

/**
 * Slow loop checking battery voltage. Also changes the D1 saturation limit
 * since that is dependent on the battery voltage.
 *
 * @return     nothing, NULL poitner
 */
void* battery_checker(__attribute__ ((unused)) void* ptr){
	double new_v;
	while(rc_get_state()!=EXITING){
		new_v = rc_adc_batt();
		// if the value doesn't make sense, use nominal voltage
		if (new_v>9.0 || new_v<5.0) new_v = V_NOMINAL;
		cstate.vBatt = new_v;
		rc_usleep(1000000 / BATTERY_CHECK_HZ);
	}
	return NULL;
}

/**
 * Call back function called by rc_mav library when Mavlink Packet is received.
 * function writes to cstate all information received from mavlink.
 */

void callback_func_any(){
	int i;
	// init variables to store data locally in function
	mavlink_att_pos_mocap_t pos_data;	// struct to contain mavlink packet data
	double q[4];				// will contain angles
	double tb[4];				// will contain angles

	// let mavlink function write to struct given by pointer
	rc_mav_get_att_pos_mocap(&pos_data);

	//update rover position
	cstate.pos_x = pos_data.x/1000;
	cstate.pos_y = pos_data.y/1000;

	for(i=0; i<4 ; i++){
		q[i] = pos_data.q[i];
	}

	//get heading
	rc_quaternion_to_tb_array(q, tb);

	cstate.heading = -tb[0];

	cstate.heading = cstate.heading + M_PI ;

	if(cstate.heading >= M_PI/2){
		cstate.heading = cstate.heading - M_PI/2;
	}
	else if(cstate.heading < M_PI/2){
		cstate.heading = cstate.heading + M_PI *3/2;
	}


	return;
}



/**
 * prints diagnostics to console this only gets started if executing from
 * terminal
 *
 * @return     nothing, NULL pointer
 */
void* printf_loop(__attribute__ ((unused)) void* ptr){
	rc_state_t last_rc_state, new_rc_state; // keep track of last state
	last_rc_state = rc_get_state();
	while(rc_get_state()!=EXITING){
		new_rc_state = rc_get_state();
		// check if this is the first time since being paused
		if(new_rc_state==RUNNING && last_rc_state!=RUNNING){
			printf("s.waypnt |");
			printf("  c.rho  |");
			printf("c.for vel|");
			printf(" c.pos x |");
			printf(" s.pos x |");
			printf(" c.pos y |");
			printf(" s.pos y |");
			printf(" s.vel   |");
			printf("c.heading|");
			printf("s.osteeri|");
			printf("s.isteeri|");
			printf("c. alpha |");
			printf("c. wp_hea|");
			printf("\n");
		}
		else if(new_rc_state==PAUSED && last_rc_state!=PAUSED){
			printf("\nPAUSED: press pause again to start.\n");
		}
		last_rc_state = new_rc_state;

		// decide what to print or exit
		if(new_rc_state == RUNNING){
			printf("\r");
			printf("%7d  |", setpoint.current_waypoint);
			printf("%7.3f  |", cstate.rho);
			printf("%7.3f  |", cstate.forward_velocity);
			printf("%7.3f  |", cstate.pos_x);
			printf("%7.3f  |", setpoint.pos_x);
			printf("%7.3f  |", cstate.pos_y);
			printf("%7.3f  |", setpoint.pos_y);
			printf("%7.3f  |", setpoint.forward_vel);
			printf("%7.3f  |", cstate.heading);
			printf("%7.3f  |", setpoint.out_steering_input);
			printf("%7.3f  |", setpoint.in_steering_input);
			printf("%7.3f  |", cstate.alpha);
			printf("%7.3f  |", cstate.wp_heading);
			printf("  ");


			//if(setpoint.arm_state == ARMED) printf("  ARMED  |");
			//else printf("DISARMED |");
			fflush(stdout);

			fprintf(fp, "%7.3f,%7.3f,%7.3f\n",cstate.pos_x,cstate.pos_y, cstate.heading);
		}
		rc_usleep(1000000 / PRINTF_HZ);
	}
	return NULL;
}
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

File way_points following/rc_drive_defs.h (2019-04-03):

/**
 * rc_drive_defs.h
 *
 * Contains the physical parameters and constraints for the edurover used in rc_drive.c
 */

#ifndef RC_DRIVE_CONFIG
#define RC_DRIVE_CONFIG


#define SAMPLE_RATE_HZ		100			// main filter and control loop speed
#define DT			(1.0/SAMPLE_RATE_HZ)	// 1/sample_rate

// Structural properties of ardurover
#define CAPE_MOUNT_ANGLE	0.49	// increase if mip tends to roll forward
#define GEARBOX			35.577	// gear ratio between motor output shaft and
#define ENCODER_RES		60	//encoder resolution per rotation (motor output shaft)
#define WHEEL_RADIUS_M		0.0425	//wheel radius in meters
#define WHEEL_SIDE_BASELINE	0.12	//wheel sideways baseline separation between axis of rotation in meters
#define WHEEL_FORWARD_BASELINE	0.17	//wheel forward baseline separation between axis of rotation in meters

//steering parameters
#define WHEEL_ANGLE_STRAIGHT	37.5	// angle in deg for wheels to be straight from 0 position (pos for lef two, neg for right two)
#define WHEEL_STRAIGHT_INPUT	0.6	// normalized input to straighten wheels over angle of 37.5deg
#define WHEEL_PI_INPUT		1.45	//scaled input to servo for 90deg rotation
#define AWD_MAX_STEERING_IN	0.3	//max steering input when in AWD Steering mode
#define AWD_MAX_STEERING_ANGLE	0.26	// max steering angle in rad.

// electrical hookups
#define MOTOR_CHANNEL_FL	1
#define MOTOR_CHANNEL_FR	2
#define MOTOR_CHANNEL_RL	4
#define MOTOR_CHANNEL_RR	3
#define MOTOR_POLARITY_FL	-1
#define MOTOR_POLARITY_FR	1
#define MOTOR_POLARITY_RR	1
#define MOTOR_POLARITY_RL	-1
#define ENCODER_CHANNEL_FL	1
#define ENCODER_CHANNEL_FR	2
#define ENCODER_CHANNEL_RL	4
#define ENCODER_CHANNEL_RR	3
#define ENCODER_POLARITY_FL	1
#define ENCODER_POLARITY_FR	-1
#define ENCODER_POLARITY_RL	1
#define ENCODER_POLARITY_RR	-1

#define SERVO_CHANNEL_FL	1
#define SERVO_CHANNEL_FR	2
#define SERVO_CHANNEL_RR	3
#define SERVO_CHANNEL_RL	4

#define SERVO_CHANNEL_GIMBAL	5

#define V_NOMINAL		7.4

// Servo Calibration Settings

#define SERVO_MAX_FL	0.8
#define SERVO_MIN_FL	-1.1
#define SERVO_VER_FL	-0.8
#define SERVO_HOR_FL	0.65
#define SERVO_CENTER_FL	-0.2


#define SERVO_CENTER_FR	-0.12

#define SERVO_CENTER_RR	-0.05

#define SERVO_CENTER_RL	-0.05



// Thread Loop Rates
#define BATTERY_CHECK_HZ	5
#define SETPOINT_MANAGER_HZ	100
#define PRINTF_HZ		10

// Navigation Parameters
#define WAYPOINT_ACCEPTANCE_RADIUS 0.3
#define KRHO 0.5 // tuning constant for velocity convergence
#define KA 1 //tuning constant for angle convergence
#define KB 0 //tuning constant for angle convergence

// Servo range parameters
#define DIST_FROM_MID_TO_FORWARD 0.55
#define DIST_FROM_MID_TO_SIDEWAYS 0.90

// forward velocity PID constants
#define D1_KP 1.5
#define D1_KI 0.00
#define D1_KD 0.0

// Mavlink Configs

#define MAVLINK_HOST_IP "192.168.1.2"
#define DEFAULT_SYS_ID 1


#endif	// endif RC_BALANCE_CONFIG
